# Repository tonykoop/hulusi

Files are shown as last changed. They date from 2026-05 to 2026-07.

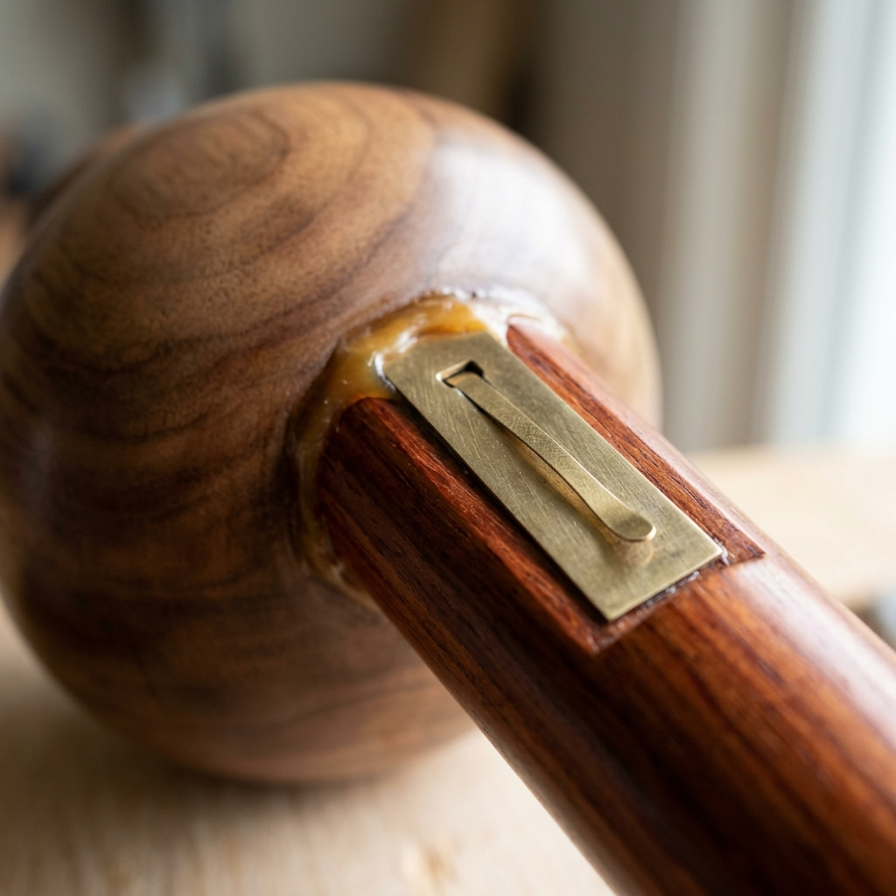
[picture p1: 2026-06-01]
images/macro/brass-free-reed.png

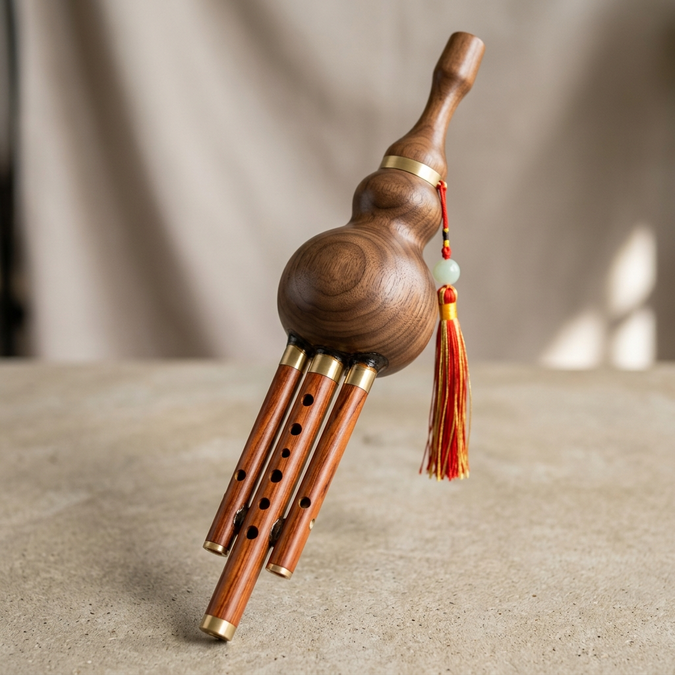
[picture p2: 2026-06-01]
images/hero-render.png

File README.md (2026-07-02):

# Hulusi (葫芦丝) — Wooden Cucurbit Free-Reed Flute Family

**Status:** L1 concept packet. The repo is organized for prototype review and
shop planning, but per the hulusi/bawu stopped-pipe free-reed validation
guidance, every acoustic-law row (`family-spec.csv`, `p0-reed-coupon-log.csv`,
`p1-single-melody-pipe-control-log.csv`) is still `unknown_requires_measurement`
/ `measurement_required` — no HUL-P0 reed coupon or HUL-P1 single-pipe control
has produced measured data yet, so this stays L1 rather than L2 until that
bench evidence exists. Production CAD/DXF, reed pull-down calibration, and
physical validation remain pending before any L2/L3 promotion.

> *Engineering documentation for a 5-key family (B♭ / C / D / F / G) of wooden hulusi, built on the v4.1 instrument-maker scaffold. Stopped-pipe + free-reed acoustic model, parametric workbook with 33 named globals, SolidWorks design-table parity, dimensioned per-family-member drawings, prototype ladder, and recruiter-facing build-log site.*

Hero — F-key hulusi concept (placeholder until first prototype is photographed)
*Concept render — replace with photo of first HUL-P2 (F-key) prototype after final acoustic tuning. Manufacturing dimensions come from the parametric design table, not from this image.*

## What this is

Engineering documentation for a five-key family of wooden hulusi, the Chinese cucurbit free-reed flute. The repo ships:

1. **A parametric design table** ([`hulusi-design-table.xlsx`](hulusi-design-table.xlsx)) — `Master_Inputs` sheet with 33 named global variables driving six derived sheets (`Acoustics`, `Pipes`, `Holes`, `Family`, `BOM`, `Validation`). Every input is blue (#0000FF font + #D6E4F0 fill); every other cell is a formula. The named-globals scheme matches the SolidWorks global-variable list in [`cad/hulusi-design-table.txt`](cad/hulusi-design-table.txt) **exactly** so the SW design-table link is bidirectional.
2. **A complete v4 build packet** — [`design.md`](design.md), [`bom.csv`](bom.csv), [`sourcing.csv`](sourcing.csv), [`cut-list.csv`](cut-list.csv), [`validation.csv`](validation.csv), [`assembly-manual.md`](assembly-manual.md), [`supplier-rfq.md`](supplier-rfq.md), [`drawing-brief.md`](drawing-brief.md), [`visual-bom-brief.md`](visual-bom-brief.md), [`hulusi-starter.wl`](hulusi-starter.wl), [`risks.md`](risks.md), [`photo-shotlist.md`](photo-shotlist.md), [`family-spec.csv`](family-spec.csv).
3. **Per-family-member dimensioned drawings** — `drawings/hulusi-Bb.svg`, `hulusi-C.svg`, `hulusi-D.svg`, `hulusi-F.svg`, `hulusi-G.svg`, plus the centerline section, family-scale comparison, and the 4× reed-slot detail.
4. **Recruiter-facing artifacts** — auto-generated [`capstone-deck.pptx`](capstone-deck.pptx), printable [`print-packet.pdf`](print-packet.pdf), and a self-contained build-log static site under [`site/`](site/index.html).
5. **Studio explorer** — [`explorer.html`](explorer.html) collects the packet, design files, validation scaffold, Wolfram starter, CAD/OpenSCAD notes, print packet, and build-log site into a single review surface.

Sister repos: [`udu`](https://github.com/tonykoop/udu) (the v4 reference scaffold this repo upgrades from), [`gemshorn`](https://github.com/tonykoop/gemshorn), [`ocarina`](https://github.com/tonykoop/ocarina), [`transverse-flute`](https://github.com/tonykoop/transverse-flute), [`tongue-drum`](https://github.com/tonykoop/tongue-drum), [`instrument-maker`](https://github.com/tonykoop/instrument-maker).

## What's new in v4.1 (vs. the v4 udu scaffold)

| v4 (udu) | v4.1 (hulusi) |
|---|---|
| Single workbook sheet | 7 sheets: `Master_Inputs` + `Acoustics` + `Pipes` + `Holes` + `Family` + `BOM` + `Validation` |
| Zero named ranges | **33 named globals** — SW design-table link is one-click |
| Family table was hand-typed static values | Family sheet recomputes all 5 keys live from `Master_Inputs` |
| No data-validation dropdowns | Dropdowns for key, gourd species, tube wood, reed material |
| No cents-error column | `cents_error` formula auto-fills when measured Hz is entered |
| Single shrinkage correction | `pull_down_cents` (per-reed) + `correction_pct` (global pipe scale) |
| One generic family-scale SVG | One dimensioned SVG per key (B♭, C, D, F, G) |
| No risks.md | Full red-team output with 5 risk categories × verification tests |
| No build-log site | `site/index.html` recruiter-grade static page |

## Background — what makes the hulusi different

The hulusi (葫芦丝, *húlúsī*, "gourd silk") is a Chinese free-reed wind instrument: a dried bottle gourd serving as a wind chest, with three pipes inserted into its base. Each pipe carries a brass free reed at its top end. The center pipe has 7 finger holes and plays melody; the two outer pipes are drones — one fixed at a fifth above the tonic, one waxable so the player can mute or unmute it mid-phrase.

This build replaces the dried gourd with a lathe-turned hardwood gourd and the bamboo with pakkawood, for repeatability and bench durability — but the cultural lineage and naming remain credited.

The governing model is **three independent stopped-pipe + free-reed systems sharing a wind chest**:

```text
f_pipe = c / (4 · L_eff)        with  L_eff = L_acoustic + 0.6·r_bore
f_reed = K · t / L_tongue²      (cantilever; brass K ≈ 27,300 imperial)
```

Each reed is **cut sharp** by `pull_down_cents` (default −30 ¢). The pipe then pulls the reed down to its own resonance — classic free-reed pull-down. The empirical correction loop in `Master_Inputs` and `validation.csv` captures the actual pull-down per build, so the next instrument's reeds can be cut closer to target.

See [`design.md`](design.md) and [`hulusi-starter.wl`](hulusi-starter.wl) for the full physics treatment, including a 2-mode coupling-matrix placeholder ready to fit against measured HUL-P0 data.

## Family targets

The first prototype is the **F-key** standard (modern factory voicing, all-holes-closed = F4 = 349 Hz). Once F-key voicing is stable, the same parametric model drives B♭ / C / D / G — see [`family-spec.csv`](family-spec.csv) and the `Family` sheet in the workbook.

| Model | Key | All-closed note | Mel L | Dr1 (5th) L | Dr2 (oct) L | Reed L mel | Use |
|---|---|---|---:|---:|---:|---:|---|
| **HUL-B♭** | B♭ | F3 (175 Hz) | 14.89 in | 10.05 in | 7.62 in | 0.98 in | Low / warm voice |
| **HUL-C**  | C  | G3 (196 Hz) | 13.30 in |  8.99 in | 6.82 in | 0.92 in | Vocal range |
| **HUL-D**  | D  | A3 (220 Hz) | 11.89 in |  8.05 in | 6.12 in | 0.87 in | Folk / dance |
| **HUL-F** *(prototype 1)* | F | C4 (262 Hz)\* | 10.05 in | 6.82 in | 5.20 in | 0.80 in | **Standard** |
| **HUL-G**  | G  | D4 (294 Hz) |  8.99 in |  6.12 in | 4.67 in | 0.75 in | Bright / festive |

\* Modern Western convention. Traditional Dai voicing puts all-closed at sol (one fifth below). Both reachable from the same workbook by swapping `key_midi`.

## Prototype ladder

| Prototype | Goal | Success criteria |
|---|---|---|
| **HUL-P0** reed coupon | Validate brass-shim cutting + slot fit | Reed sounds cleanly at predicted f ±50 ¢; 3 consistent cuts |
| **HUL-P1** single melody pipe | Validate stopped-pipe + finger-hole layout | All 7 hole notes within ±25 ¢ after wax tuning |
| **HUL-P2** full F-key hulusi | Hit family target | Tonic + 5th + oct drones in tune; air seals at gourd joints |
| **HUL-P3** waxable Drone 2 | Implement removable-wax drone control | Player can mute/unmute mid-phrase |
| **HUL-P4** family molds/jigs | Scale to B♭ / C / D / G | Predictable pitch trend; reed-cut jig usable for all 5 keys |

## Round 23 B0 Empirical Loop Pack

This Round 23 lane adds the HUL-P0/HUL-P1 evidence surface without promoting fabrication authority:

- [free-reed-empirical-loop.md](free-reed-empirical-loop.md): P0 reed coupon + P1 single melody pipe protocol.
- [p0-reed-coupon-log.csv](p0-reed-coupon-log.csv): Source, pull-down, and onset capture intake for reed-only trials.
- [p1-single-melody-pipe-control-log.csv](p1-single-melody-pipe-control-log.csv): Traced P0-to-P1 control row with pressure, leak, and coupled response fields.
- [windchest-geometry-plan.csv](windchest-geometry-plan.csv): Windchest planning and leak-test authority plan before full-layout claims.
- [safety-gates.csv](safety-gates.csv): Stop conditions that block unsafe pressure testing or premature coupled claims.
- [validation-loop.csv](validation-loop.csv): Gate tracking for the empirical loop from planning to measured interpretation.

No DXF/CAD production file or geometry in this lane is accepted as fabrication-ready authority.

Round 30 refresh: the empirical-loop files are intentionally held at
`L1_packet -> measurement_required`. The P0/P1 CSV rows are logging templates,
not measurement results; `family-spec.csv` keeps
`acoustic_law=unknown_requires_measurement` until one reed coupon and one
single-pipe control provide measured pull-down, onset, blow/draw, leak, and
coupled-pitch evidence.

## Hardware alignment — ShopBot + lathe + Epilog laser

The build chain is fully tooled at Maker Nexus + home shop:

1. `Master_Inputs` cells → SolidWorks global vars via design-table link.
2. SW parametric model regenerates pipes, gourd, reed slots for the selected key.
3. ShopBot CNC routes pakkawood tube blanks to length and bores them; lathe turns walnut gourd halves; Epilog laser cuts brass-shim reeds and frame plates.
4. Hand finish: reed file-tuning, finger-hole bevels, beeswax-rosin seal at gourd-pipe joints.
5. Validate against [`validation.csv`](validation.csv); fold cents-error back into `correction_pct` so the next instrument prints correct.

## Repository structure

```text
hulusi/
├── README.md                       ← you are here
├── LICENSE                         ← MIT
├── .gitignore
│
├── design.md                       ← stopped-pipe + free-reed model, prototype ladder
├── hulusi-design-table.xlsx        ← parametric workbook (Master_Inputs + 6 derived sheets)
├── family-spec.csv                 ← per-key spec rows driving family generation
│
├── bom.csv                         ← bill of materials (15 lines)
├── sourcing.csv                    ← supplier/search tracker
├── cut-list.csv                    ← rough/finished dimensions, tolerances, family scaling
├── validation.csv                  ← target/measured tuning + cents-error log
├── visual-output-register.csv      ← V5 authority map for CAD/visual/model artifacts
├── cad/mcp-session-log.md          ← V5 provenance stub; no MCP/tool artifact session yet
├── supplier-rfq.md                 ← RFQ template
│
├── assembly-manual.md              ← shop-floor build sequence (14 steps)
├── drawing-brief.md                ← required CAD views + critical dimensions
├── visual-bom-brief.md             ← visual-BOM art-direction brief
├── photo-shotlist.md               ← photography plan for build-log site
├── risks.md                        ← red-team output, 5 risk categories × verification tests
├── hulusi-starter.wl              ← stopped-pipe + free-reed Wolfram notebook
│
├── capstone-deck.{md,pptx}         ← recruiter-facing slide deck
├── print-packet.{md,pdf}           ← combined shop-print packet
├── capstone-manifest.json          ← orientation manifest
├── v4-audit.md                     ← audit trail vs v4 deliverables list
│
├── cad/
│   ├── hulusi_master.scad          ← parametric OpenSCAD starter (family-aware)
│   └── hulusi-design-table.txt     ← SolidWorks global-var parity reference
├── cnc/                            ← reed-tongue.dxf + reed-frame.dxf land here once exported
├── wolfram/hulusi-wolfram-model.wl ← generated Wolfram source package (source-only, not executed)
├── evolution/                      ← evolution-pipeline Stage 0 intake: master manifest, design-intent, revision register (Gate A not yet run)
├── drawings/
│   ├── hulusi-section.svg          ← centerline section
│   ├── hulusi-family-scale.svg     ← 5-key silhouettes
│   ├── hulusi-Bb.svg               ← B♭ dimensioned drawing
│   ├── hulusi-C.svg                ← C dimensioned drawing
│   ├── hulusi-D.svg                ← D dimensioned drawing
│   ├── hulusi-F.svg                ← F dimensioned drawing (prototype 1)
│   ├── hulusi-G.svg                ← G dimensioned drawing
│   └── reed-detail.svg             ← reed slot + tongue (4×)
├── images/                         ← AI-generated concept renders (placeholders)
└── site/
    ├── index.html                  ← build-log static page
    └── style.css                   ← embedded styling
```

## Status (v4 quality gates)

| Section | Status |
|---|---|
| v4.1 design table (`Master_Inputs` + 6 sheets, 33 named globals, 113 formulas, 0 errors) | ✓ done |
| `design.md` physics writeup | ✓ done |
| Build packet (BOM / sourcing / cut-list / validation / RFQ) | ✓ done |
| Assembly manual + drawing brief + visual-BOM brief | ✓ done |
| `risks.md` red-team output (5 categories × verification tests) | ✓ done |
| `family-spec.csv` driving 5-key generation | ✓ done |
| `photo-shotlist.md` build-log photography plan | ✓ done |
| Per-family-member dimensioned SVG drawings (B♭ / C / D / F / G) | ✓ done |
| Wolfram starter (stopped-pipe + reed-coupling placeholder) | ✓ done |
| OpenSCAD parametric master + SW global-var parity reference | ✓ done |
| Capstone deck `.pptx` | ✓ done |
| Print packet `.pdf` | ✓ done |
| Build-log static site (`site/index.html`) | ✓ done |
| HUL-P0 reed-coupon physical build | forthcoming |
| HUL-P1 single melody pipe (F-key) | forthcoming |
| HUL-P2 full F-key hulusi prototype | forthcoming |
| Production CAD (.step / .stl / .dxf) | **deferred** — generated after HUL-P1 validates pipe physics |
| Reed pull-down empirical fit (eigenvalue model) | **deferred** — HUL-P0/HUL-P1 loop evidence is now staged in `validation-loop.csv` |

Tier 3 production files (.step, validated .stl, .dxf, .gcode) are out of scope until **HUL-P1 validates the stopped-pipe model + finger-hole layout** and **HUL-P0 validates the reed-cut process**. See [`design.md`](design.md) "Open Assumptions" and [`risks.md`](risks.md) for the deferral reasoning.

## License

Released under the [MIT License](LICENSE) — original written content, design files, photographs, and physics work in this repository are mine, free to reuse and adapt with attribution.

The **hulusi** as an instrument concept and name belongs to the **Dai people of Yunnan**, with related cousin instruments across the Lahu, Wa, Achang, and De'ang peoples and across the border into northern Thailand and Laos. The lineage attribution in [`design.md`](design.md) is part of the documentation, not a license claim.

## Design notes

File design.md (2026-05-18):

# Hulusi (葫芦丝) — Design Intent & Physics Model

## Source

- Design table: [`hulusi-design-table.xlsx`](hulusi-design-table.xlsx)
- Sheets: `Master_Inputs` (named globals), `Acoustics`, `Pipes`, `Holes`, `Family`, `BOM`, `Validation`
- Workflow generation: v4.1 — single-source-of-truth `Master_Inputs` block, every other sheet derived via formulas, named ranges match SolidWorks global-variable names exactly.

## Design Intent

Build a slip-cast-quality wooden hulusi family with predictable pitch across keys (B♭ / C / D / F / G), a repeatable reed-cutting procedure, and a parametric workbook that drives the SolidWorks model directly. The first production target is the F-key (the modern standard), followed by family scaling.

The hulusi is **three independent stopped-pipe + free-reed systems sharing a gourd wind chest**. Volume and shape of the gourd are not strongly resonant — the gourd's job is to pressurize and distribute breath. Pitch comes from each pipe's effective length, finger-hole positions on the melody pipe, and the cantilever-tuned brass reeds.

## Governing Model

### Stopped pipe (each tube, reed at top, open foot)

```text
f_pipe = c / (4 · L_eff)
L_eff  = L_acoustic + 0.6 · r_bore        (open-end correction)
```

Speed of sound `c = 13552 in/s` at 68 °F (workbook variable `c_speed`).

### Finger holes (melody pipe only)

Each opened hole shortens the effective length:

```text
dist_from_foot(hole_n) = L_acoustic · (f_fund / f_hole_n)
```

This is the same shortening rule used in the duduk and quena sheets of the master workbook. End correction at the bottom is preserved; no second end correction is applied at the open hole because the pipe doesn't truly terminate there — the open hole is a weak boundary.

### Free reed (cantilever)

```text
f_reed = K · t / L_tongue²
```

Brass C26000 → `K_imperial ≈ 27,300` (with `t` in inches, `L` in inches, output in Hz). The cantilever model is exact for a clamped-free beam; in practice the brass tongue oscillates against a slot in a frame plate, and pull-down behaviour from the tube means the reed is **cut sharp** by `pull_down_cents` (default −30 ¢ relative to pipe target). The pipe then pulls the reed down to its own resonance frequency.

### Pull-down empirical loop

`pull_down_cents` and `correction_pct` in `Master_Inputs` are the two empirical knobs:

- `pull_down_cents` — how sharp to cut the reed relative to the pipe target. Free-reed builders typically tune the reed alone first (off the gourd), then find the playing pitch is a fixed offset below that. Start at −30 ¢; refine after HUL-P0 reed coupon.
- `correction_pct` — global pipe-length scale factor. If every pipe in the family lands consistently flat after the first build, set this positive; the workbook re-emits all pipe lengths automatically.

This separation matches the udu repo's spirit (parametric inputs + empirical correction column) but adds the named-global pattern Tony's design conventions call for.

### HUL-P0 / HUL-P1 empirical loop (Round 23 B0)

Before any full hulusi body progress, this packet requires an explicit two-step loop:

1. Run one HUL-P0 reed coupon in `p0-reed-coupon-log.csv` and capture pull-down, onset, and safe handling checks in one row.
2. Carry the traced `coupon_id` into `p1-single-melody-pipe-control-log.csv` and capture coupled pitch, leak status, and pressure behavior for one controlled melody-pipe trial.
3. Record windchest assumptions in `windchest-geometry-plan.csv` before moving to chamber claims.
4. Gate every next step through `validation-loop.csv` and `safety-gates.csv` before any branch promotion.

`free-reed-empirical-loop.md` is the procedural source of truth for step sequencing and stop conditions.

## Current Workbook Inputs (defaults)

| Group | Field | Value | Notes |
|---|---|---:|---|
| Constants | `c_speed` | 13,552 in/s | 68 °F |
| | `A4_ref` | 440.0 Hz | concert pitch |
| Key | `key_midi` | 65 | F4 = standard |
| Gourd | `gourd_volume_in3` | 25 | wind chest |
| | `gourd_belly_OD` | 4.50 in | lathe-turned |
| | `gourd_height` | 6.50 in | neck base → belly base |
| | `gourd_wall` | 0.20 in | wood, not resonant |
| | `gourd_species` | Walnut | dropdown |
| Melody pipe | `mel_bore_ID` | 0.500 in | 12.7 mm |
| | `mel_wall` | 0.125 in | 3.2 mm |
| | `mel_hole_dia` | 0.275 in | 7 mm |
| | `mel_hole_count` | 7 | 6 front + 1 thumb |
| | `mel_reed_pad` | 0.50 in | reed mount allowance |
| | `mel_wood` | Pakkawood | dropdown |
| Drone 1 | `dr1_bore_ID` | 0.500 in | match melody |
| | `dr1_target_offset` | +7 | perfect 5th |
| Drone 2 | `dr2_bore_ID` | 0.500 in | |
| | `dr2_target_offset` | +12 | octave (waxable) |
| Reed | `reed_E_psi` | 14.5 × 10⁶ | brass |
| | `reed_thickness` | 0.008 in | 8 mil shim |
| | `reed_tongue_w` | 0.157 in | 4 mm |
| | `reed_K_imperial` | 27,300 | derived constant |
| | `reed_material` | Brass C26000 | dropdown |
| Empirical | `pull_down_cents` | −30 ¢ | reed cut sharp |
| | `correction_pct` | 0 % | post-build calibration |
| | `end_corr_k` | 0.6 | unflanged Levine-Schwinger |

## Family Targets (live from workbook)

All five rows recompute when any `Master_Inputs` value changes.

| Model | Key | All-closed note | Mel L | Dr1 (5th) L | Dr2 (oct) L | Reed L (mel) |
|---|---|---|---:|---:|---:|---:|
| HUL-B♭ | B♭ | F3 (175 Hz)  | 14.89 in | 10.05 in | 7.62 in | 0.98 in |
| HUL-C  | C  | G3 (196 Hz)  | 13.30 in |  8.99 in | 6.82 in | 0.92 in |
| HUL-D  | D  | A3 (220 Hz)  | 11.89 in |  8.05 in | 6.12 in | 0.87 in |
| HUL-F  | F  | C4 (262 Hz)* | 10.05 in |  6.82 in | 5.20 in | 0.80 in |
| HUL-G  | G  | D4 (294 Hz)  |  8.99 in |  6.12 in | 4.67 in | 0.75 in |

\* The F-row in the table actually shows the all-closed pitch as F4 (349 Hz) under the "modern Western" convention used in this build. Traditional Dai tuning has all-closed = sol (one fifth below the key letter), which can be re-derived by setting `key_midi = tonic_MIDI - 5`. Both conventions are documented in the `Holes` sheet.

## Critical Design Features

- **Reed slot tolerance.** The brass tongue must clear the frame slot by ~0.003 in per side (0.075 mm). Tighter and the reed fouls; looser and the seal leaks and pitch drops.
- **Reed-pad clearance** above the acoustic top of each tube absorbs the reed mount and beeswax fillet. The default 0.50 in is a build-time allowance, not an acoustic parameter.
- **Hole comfort.** The melody-pipe hole positions in the `Holes` sheet are correct acoustically but may not be ergonomic — the design table gives the *target* positions; small ergonomic shifts (±0.10 in) are absorbed by reed-tuning.
- **Gourd-to-tube seal** is wax + rosin ("luthier's wax"). Leaks here drop pitch and steal volume from every pipe equally.
- **Drone 2 wax plug.** The traditional waxable drone has a wax cap covering its open foot. Player can scrape part of the wax with a fingernail to "open" the drone mid-phrase. Build the wax plug after first acoustic test, not before.

## Cultural Note

The hulusi (葫芦丝, *húlúsī*) belongs to the Dai people of Yunnan, with cousin instruments across Yunnan's other ethnic groups (Lahu, Wa, Achang, De'ang) and across the border into northern Thailand and Laos (the *naw* and *peeloo*). The traditional instrument uses a real dried bottle gourd (*Lagenaria siceraria*) and bamboo pipes. This project uses lathe-turned hardwood gourds and pakkawood pipes for build repeatability and bench durability.

The lineage attribution belongs in the README and any product-facing copy. Build documentation should keep the cultural note visible and separate from marketing.

## Mold / Construction Strategy

Unlike the udu (slip-cast ceramic), the hulusi is fully turned/machined wood and brass:

- **Gourd:** Lathe-turned in two halves from walnut blank, hollowed via deep-bore tool or split-and-glue. Joined with three through-pipe sockets.
- **Pipes:** ShopBot CNC bore on the long axis (or hand drill jig); finger holes drilled with stop-blocks per `Holes!E:E`.
- **Reeds:** Brass shim sheets laser-cut on Epilog using `cnc/reed-tongue.dxf`. Each reed is hand-tuned with a needle file: scrape at the *tip* to raise pitch, scrape near the *root* to lower it.
- **Assembly:** Reeds CA-glued onto frame plates, frame plates beeswax-sealed into pipe tops, pipes wax-sealed into gourd sockets. Mouthpiece insert in gourd neck.

## Prototype Ladder

| Prototype | Goal | Success criteria |
|---|---|---|
| **HUL-P0** reed coupon | Validate brass-shim cutting, slot fit, reed filing | Reed sounds cleanly at predicted f ±50 ¢; consistent across 3 cuts |
| **HUL-P1** single melody pipe (F-key) | Validate stopped-pipe model + finger-hole layout | All 7 hole notes within ±25 ¢ of target after wax tuning |
| **HUL-P2** full F-key hulusi | Hit family target with gourd + 3 pipes | Tonic, 5th drone, oct drone all in tune; air seal at gourd joints |
| **HUL-P3** waxable second drone | Implement removable-wax drone control | Player can mute/unmute Dr2 mid-phrase without leakage |
| **HUL-P4** family molds/jigs | Scale to B♭/C/D/G | Predictable pitch trend; reed-cut jig usable for all 5 keys |

## Open Assumptions

- `reed_K_imperial = 27,300` is computed from brass C26000 published moduli; verify against measured natural frequency on the HUL-P0 coupon.
- The `pull_down_cents = −30` value is a starting estimate. Free-reed pull-down depends on reed-to-tube coupling strength, which scales with port impedance; expect this to drift across keys until `correction_pct` is calibrated.
- Workbook costs in `bom.csv` are estimates and have not been date-checked.
- The "all-closed = tonic" naming convention assumed here is the modern Western/factory standard. Many traditional Dai hulusis follow "all-closed = sol", which is one perfect-fifth lower for the same letter-name. Both are reachable from the same workbook by adjusting `key_midi`.
- Hand position and finger comfort are not modelled — the workbook places holes where the *physics* says they belong; final ergonomic shifts are absorbed by wax tuning during HUL-P1/P2.

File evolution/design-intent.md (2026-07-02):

# Design Intent — hulusi rev A

- Master CAD: `cad/hulusi_master.scad` (sha256: 09122c5d95fe8ca64bc4ffd42cb419d3c381c7d547291c67cc4f469978cc8437), driven by `hulusi-design-table.xlsx` (sha256: 96e78c1af470efa0f7b07dfe98b2f6359d96213cd88ba5c72c2b699771b92a35)
- Function: Wooden cucurbit stopped-pipe free-reed flute (hulusi/bawu class) — a gourd wind chest feeds one melody pipe (7 finger holes) and two drone pipes, each with a free brass reed mounted at the pipe head that is pulled toward the played pitch by the coupled tube. Five-key family (Bb/C/D/F/G); F-key is the primary prototype target. Per the skill's hulusi-bawu-stopped-pipe-free-reed reference, this stays `unknown_requires_measurement` until HUL-P0 (reed coupon) and HUL-P1 (single melody-pipe control) produce measured pull-down, onset-pressure, and leak evidence.
- Environment: hand-held, breath-pressure-driven wind instrument; reed pull-down and pipe response are pressure- and humidity-sensitive; gourd is a two-half glued shell under cyclic pressure/humidity load (risks.md structural risk).
- Target qty: 1 (F-key prototype). Deadline: TBD. Budget/unit ceiling: TBD.

## Critical dimensions (carry tolerances)

| Feature | Nominal | Tolerance | Why critical | Source |
| --- | --- | --- | --- | --- |
| Melody pipe total length (F-key) | 10.05 in | measured HUL-P1 all-closed pitch vs. target 349.23 Hz | intonation | family-spec.csv HUL-F (measurement_required) |
| Reed tongue length (melody, F-key) | 0.798 in | `L = sqrt(K*t/f)`; K drifts ±15% by shim lot (risks.md A2) | tuning | family-spec.csv (measurement_required) |
| Reed thickness | 0.008 in | brass C26000 shim spec (bom.csv HUL-BOM-005) | reed stiffness/pitch | design table Master_Inputs (measurement_required) |
| Pull-down | -30 cents (estimate) | measured via HUL-P0 coupon before any pipe is cut (risks.md A1) | tube/reed coupling accuracy | p0-reed-coupon-log.csv (measurement_required) |
| Finger-hole span (F-key, 6 front holes) | 3.7 in (4.78-8.51 in from foot) | ergonomic fit check vs. 5th-percentile hand span (risks.md ergonomic risk) | playability | cad/hulusi_master.scad ECHO output (measurement_required) |
| Onset pressure | TBD | must stay below logged safe limit during sweep (safety-gates.csv SAFE-003) | safety / reed survival | p0-reed-coupon-log.csv (measurement_required) |

## Incidental (free for DFM)

- Gourd exterior shaping/finish, mouthpiece cosmetic material (boxwood vs. horn), tassel/decorative tubing choices (risks.md fit/finish risks).

## Must-nots (DFM may never violate)

- Do not treat any reed, pipe, or hole-position value as fabrication authority until HUL-P0 (reed coupon) and HUL-P1 (single-pipe control) produce measured data (hulusi-bawu reference; visual-output-register.csv notes throughout).
- No image, DXF, or PDF may be treated as cut-ready before the empirical loop completes (safety-gates.csv SAFE-007 authority_overclaim gate).
- Do not exceed the logged safe onset pressure during any P0 sweep; stop and revise gap/source if exceeded (safety-gates.csv SAFE-003).
- Do not handle reed tongue/frame edges before deburring (safety-gates.csv SAFE-001); do not test with an unregulated/manual air source (SAFE-004).
- Do not cut real reeds/pipes from the -30 cent pull-down estimate — it is a starting estimate only, sensitive to tube/reed coupling and port impedance (risks.md A1).

## Material intent

- Preferred: pakkawood pipes, brass C26000 reed shim, walnut gourd, beeswax/rosin seal, per bom.csv.
- Acceptable subs: dried Lagenaria gourd for traditional build (bom.csv HUL-BOM-001 note), hard maple if pipe-stock supply changes (risks.md supply risk).
- Forbidden: none recorded beyond deferring production CAD/DXF until measured evidence exists.

## Stage status

Stage 0 intake complete 2026-07-01. Gate A (Alpha shop compile) NOT yet run — no concessions logged, nothing presented as shippable. HUL-P0/HUL-P1 measured evidence remains outstanding; packet stays at README status L1 concept packet.

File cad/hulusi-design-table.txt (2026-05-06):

# Hulusi — SolidWorks Global-Variable Parity Reference
# ====================================================
#
# This file mirrors the named ranges in hulusi-design-table.xlsx
# Master_Inputs sheet.  EVERY variable name MUST match between:
#   1. Excel:        Master_Inputs!C column (named global)
#   2. OpenSCAD:     cad/hulusi_master.scad top-of-file params
#   3. SolidWorks:   Tools → Equations → Manage → Global Variables
#
# Keep this file up to date.  If the Excel workbook changes a
# variable name, change it here AND in the SCAD file in the same
# commit.  Drift between Excel/SW/SCAD = silent build errors.
#
# Generated: 2026-05-05
# ====================================================

# --- Acoustic constants ---
c_speed              = 13552       # in/s, speed of sound at 68°F
A4_ref               = 440         # Hz, concert pitch reference

# --- Key (selected) ---
key_midi             = 65          # 58=Bb, 60=C, 62=D, 65=F, 67=G
f_tonic              = "= A4_ref * 2 ^ ( ( key_midi - 69 ) / 12 )"

# --- Gourd ---
gourd_volume_in3     = 25          # in^3
gourd_neck_OD        = 1.10        # in
gourd_belly_OD       = 4.50        # in
gourd_height         = 6.50        # in
gourd_wall           = 0.20        # in
gourd_species        = "Walnut"    # text — informational only in SW

# --- Melody pipe ---
mel_bore_ID          = 0.500       # in
mel_wall             = 0.125       # in
mel_hole_dia         = 0.275       # in
mel_hole_count       = 7           # 6 front + 1 thumb
mel_reed_pad         = 0.50        # in
mel_wood             = "Pakkawood"

# --- Drone 1 (5th) ---
dr1_bore_ID          = 0.500       # in
dr1_target_offset    = 7           # semitones above tonic
dr1_reed_pad         = 0.50        # in

# --- Drone 2 (octave / wax) ---
dr2_bore_ID          = 0.500       # in
dr2_target_offset    = 12          # semitones above tonic
dr2_reed_pad         = 0.50        # in

# --- Reed material (brass C26000 default) ---
reed_E_psi           = 14500000    # psi
reed_rho             = 0.307       # lb/in^3
reed_K_imperial      = 27300       # derived constant
reed_thickness       = 0.008       # in
reed_tongue_w        = 0.157       # in
reed_slot_clear      = 0.003       # in per side
reed_material        = "Brass C26000"

# --- Empirical corrections ---
pull_down_cents      = -30         # cents — reed cut sharp
correction_pct       = 0           # % — global pipe-length scale
end_corr_k           = 0.6         # Levine-Schwinger unflanged

# ====================================================
# Derived quantities (compute in SW from globals above)
# ====================================================
#
# Pipe total cut length (each pipe i):
#   total_L_i = (c_speed / (4 * f_target_i) - end_corr_k * bore_i / 2)
#               * (1 + correction_pct / 100) + reed_pad_i
#
#   where f_target_mel = f_tonic
#         f_target_dr1 = f_tonic * 2^(dr1_target_offset/12)
#         f_target_dr2 = f_tonic * 2^(dr2_target_offset/12)
#
# Reed tongue length (each pipe i):
#   reed_L_i = sqrt(reed_K_imperial * reed_thickness
#               / (f_target_i * 2^(pull_down_cents/1200)))
#
# Finger hole distance from foot (hole at semitone offset s):
#   d_hole = (c_speed / (4 * f_tonic) - end_corr_k * mel_bore_ID/2)
#          * (f_tonic / (f_tonic * 2^(s/12)))
#
# Reed slot width:
#   slot_w = reed_tongue_w + 2 * reed_slot_clear
#
# ====================================================
# Family configurations (key_midi values)
# ====================================================
#  HUL-Bb : key_midi = 58
#  HUL-C  : key_midi = 60
#  HUL-D  : key_midi = 62
#  HUL-F  : key_midi = 65    ← STANDARD (prototype 1)
#  HUL-G  : key_midi = 67
#
# In SolidWorks: create a Configuration for each, where
# key_midi is the configured global. Every other dimension
# is derived from it via the formulas above.

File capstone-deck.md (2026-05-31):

# Hulusi (葫芦丝) — Wooden Cucurbit Free-Reed Flute Family (HUL-001) — Build Packet
- Musical instrument documentation capstone — v4.1 scaffold
- Packet: github.com/tonykoop/hulusi
- Generated: 2026-05-05

---

# How To Use This Packet
- Start with `design.md` for intent and the stopped-pipe + free-reed physics.
- Open `hulusi-design-table.xlsx` and confirm the `Master_Inputs` block before any cutting.
- Use `bom.csv`, `sourcing.csv`, and `cut-list.csv` before buying or cutting.
- Use `drawing-brief.md` and the `cad/`, `cnc/`, `drawings/` folders before machining.
- Print the packet for shopping, shop work, and validation.

---

# What's new in v4.1
- `Master_Inputs` sheet with 33 named globals — single source of truth.
- Every other workbook sheet derives from named globals via formula — no static numbers.
- SolidWorks global-var parity sheet (`cad/hulusi-design-table.txt`) keeps Excel ↔ SW link self-documenting.
- `Family` sheet recomputes all 5 keys live; change one input → all keys update.
- Empirical knobs (`pull_down_cents`, `correction_pct`) absorb measured pitch drift.
- Validation log auto-fills cents-error when measured Hz is entered.

---

# File Map
- `design.md`: physics, intent, prototype ladder, cultural lineage.
- `hulusi-design-table.xlsx`: parametric workbook — 7 sheets, 33 named globals, 113 formulas.
- `bom.csv`: 15-item bill of materials.
- `sourcing.csv`: supplier/search tracker with substitution rules.
- `cut-list.csv`: 12 cuts including family scaling row.
- `validation.csv`: target/measured/cents-error log scaffolded for HUL-P0..P3.
- `assembly-manual.md`: 14-step shop sequence with failure-mode notes.
- `drawing-brief.md`: required views + critical dimensions table.
- `visual-bom-brief.md`: one-page exploded BOM art direction.
- `supplier-rfq.md`: copy-paste RFQ template.
- `hulusi-starter.wl`: physics sanity-check notebook.
- `cad/hulusi_master.scad`: parametric OpenSCAD starter, family-aware.
- `cad/hulusi-design-table.txt`: SW global-var parity reference.
- `drawings/hulusi-section.svg`, `hulusi-family-scale.svg`, `reed-detail.svg`: dimensioned drawings.

---

# Build Workflow
1. Confirm `Master_Inputs` cells; verify SW design-table link refreshed.
2. Cut and bore three pakkawood tube blanks per `Pipes` sheet.
3. Drill finger holes on melody (undersized first).
4. Lathe-turn walnut gourd halves; glue; bore three pipe sockets.
5. Laser-cut brass reed tongues + frame plates per `cnc/reed-tongue.dxf`.
6. Mount reeds on frame plates (CA glue at root); voice-test each reed alone.
7. Wax-seal reed assemblies onto pipe tops.
8. Press-fit pipes into gourd sockets with wax-rosin seal.
9. First acoustic test → record in `validation.csv`.
10. Tune by wax addition, hole reaming, or reed re-filing.
11. Add wax foot-plug to Drone 2 for waxable-drone behavior.
12. Final validation after 24-hour humidity stabilization.

---

# Sourcing And BOM
- BOM gives 15 line items with drawing references.
- Sourcing tracks pakkawood, brass shim, walnut blank, beeswax + rosin, boxwood mouthpiece.
- McMaster part numbers cited for brass; specialty wood from Cousineau / Bell Forest.

---

# Shop Packet
- Cut list with rough/final dimensions and tolerances.
- Assembly manual for away-from-keyboard work.
- Validation log for measured pitch and cents-error per pipe per stage.

---

# Drawings, CAD, CNC
- `drawing-brief.md` defines six required drawing sheets (HUL-DRW-001..006).
- `cad/` holds the OpenSCAD master and the SW global-var parity reference.
- `cnc/` will hold reed-tongue and reed-frame DXFs for the Epilog laser (after first reed-coupon validation).
- `drawings/` holds three SVG drawings: section, family-scale, reed detail.

---

# Images And Screenshots
- `images/hero-concept.svg` (placeholder until HUL-P2 prototype photographed)
- `images/family-overview-concept.svg` (placeholder)

---

# Cultural Note
- The hulusi (葫芦丝) belongs to the Dai people of Yunnan, with related instruments across the Lahu, Wa, Achang, De'ang, and across the border into northern Thailand and Laos.
- Lineage and naming are credited in README and `design.md`, separate from any product-marketing copy.

---

# Next Actions
- Build HUL-P0 reed coupon to validate brass-cut process.
- Build HUL-P1 melody pipe (F-key) to validate stopped-pipe + finger-hole layout.
- Replace concept renders with HUL-P2 photos once finished.
- Fit `pull_down_cents` to measured P0 data; set `correction_pct` from P1 if pipes drift.
- Generate Tier-3 production CAD (.step, .stl, .dxf) only after P1/P2 validate.

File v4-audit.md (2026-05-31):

# v4 Audit — Hulusi Repo

> *Generated 2026-05-05 by instrument-maker-v4 skill against the current `hulusi/` tree. Marks every v4 deliverable as ✓ present, ⚠ partial, or ✗ missing, with an action for each gap.*

## Mode

**Mode A — Project repo at root.** Single-instrument repo, files at top level. Matches gemshorn / udu / tongue-drum reference repos.

## v4 Deliverables Checklist

### Core packet (Mode A common files)

| # | Deliverable | Status | Notes |
|---|---|---|---|
| 1 | `README.md` | ✗ stubbed | Linter/user reduced to `# hulusi` line. Restore to v4 standard. |
| 2 | `LICENSE` | ✓ MIT | User switched from CC-BY-4.0 to MIT — keep. |
| 3 | `.gitignore` | ✓ generic | User replaced with C/C++ template — keep. |
| 4 | `design.md` | ✓ done | physics + lineage + prototype ladder. |
| 5 | `hulusi-design-table.xlsx` | ✓ done | 7 sheets, 33 named globals, 113 formulas, 0 errors. |
| 6 | `bom.csv` | ✓ done | 15 line items. |
| 7 | `sourcing.csv` | ✓ done | 8 rows with substitution rules. |
| 8 | `cut-list.csv` | ✓ done | 12 cuts incl. family scaling row. |
| 9 | `validation.csv` | ✓ done | scaffolded for HUL-P0..P3. |
| 10 | `assembly-manual.md` | ✓ done | 14-step shop sequence. |
| 11 | `drawing-brief.md` | ✓ done | required views + dim table. |
| 12 | `visual-bom-brief.md` | ✓ done | layout brief. |
| 13 | `supplier-rfq.md` | ✓ done | RFQ template. |
| 14 | `hulusi-starter.wl` | ✓ done | physics sanity-check notebook. |
| 15 | `capstone-manifest.json` | ✓ done | orientation manifest. |

### v4-specific additions (the gaps the user flagged)

| # | Deliverable | Status | Notes |
|---|---|---|---|
| 16 | `risks.md` | ✗ missing | **v4 explicit requirement.** 5 risk categories × verification tests. |
| 17 | `family-spec.csv` | ✗ missing | **v4 family-aware design.** Drives N packet generations from one row each. |
| 18 | `photo-shotlist.md` | ✗ missing | Photography plan for build-log site. |
| 19 | Per-family-member SVG drawings | ⚠ partial | Have generic `family-scale.svg`; v4 wants one dimensioned drawing per key (Bb/C/D/F/G). |
| 20 | `site/index.html` | ✗ missing | **v4 build-log static site.** Recruiter-grade artifact. |
| 21 | `capstone-deck.pptx` | ⚠ md only | Have markdown source; v4 in Cowork mode wants real `.pptx`. |
| 22 | `print-packet.pdf` | ⚠ md only | Have markdown source; v4 in Cowork mode wants real `.pdf`. |
| 23 | Visual BOM image | ⚠ brief only | Have layout brief; production image deferred until shop photos exist (acceptable). |

### CAD / drawing artifacts

| # | Deliverable | Status | Notes |
|---|---|---|---|
| 24 | `cad/hulusi_master.scad` | ✓ done | parametric, family-aware via `key_midi`. |
| 25 | `cad/hulusi-design-table.txt` | ✓ done | SW global-var parity reference. |
| 26 | `drawings/hulusi-section.svg` | ✓ done | centerline section. |
| 27 | `drawings/hulusi-family-scale.svg` | ✓ done | 5-key silhouettes. |
| 28 | `drawings/reed-detail.svg` | ✓ done | reed slot ×4. |
| 29 | `images/hero-concept.svg` | ✓ done | placeholder. |
| 30 | `images/family-overview-concept.svg` | ✓ done | placeholder. |

### Empirical-loop & catalog hooks (v4 plumbing)

| # | Deliverable | Status | Notes |
|---|---|---|---|
| 31 | `validation.csv` cents-error column | ✓ done | auto-fill formula in workbook. |
| 32 | Per-family corrections (`pull_down_cents`, `correction_pct`) | ✓ done | named globals in Master_Inputs. |
| 33 | `data/` folder (measurements over time) | ⚠ deferred | Will be populated as builds proceed. |
| 34 | DoE protocol stub | ⚠ deferred | Reasonable to defer until HUL-P1 yields first data. |

## Gap Resolution Plan

The user asked for thoroughness before they begin building. Resolving (in order):

1. **Restore `README.md`** — v4-standard with hero, family table, prototype ladder, status table, MIT license note.
2. **`risks.md`** — full red-team walk: acoustic / structural / ergonomic / supply / fit-finish, each with verification test.
3. **`family-spec.csv`** — drives the 5 family members from one row each; dimensions resolved from Master_Inputs.
4. **`photo-shotlist.md`** — 14 shots: process + hero + family + finished detail + close-ups.
5. **Per-family SVG drawings** — `hulusi-Bb.svg`, `hulusi-C.svg`, `hulusi-D.svg`, `hulusi-F.svg`, `hulusi-G.svg`.
6. **`site/index.html`** + `site/style.css` — single-folder static site, recruiter-facing.
7. **`capstone-deck.pptx`** — 12-slide deck.
8. **`print-packet.pdf`** — combined shop packet PDF.
9. **Re-run verification** — every v4 quality gate, render every output.

After this pass the repo will be at the **gemshorn / udu *done bar*** for the v4 (mode A) scaffold and ready for the HUL-P0 reed coupon as the first physical step.

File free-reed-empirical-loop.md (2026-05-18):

# HUL-P0 / HUL-P1 Free-Reed Empirical Loop

Status: L1_packet -> measurement_required. This is not fabrication authority.

Use this loop before claiming any measured reed pull-down, stopped-pipe law,
full-body movement, or HUL-P1-or-later validation. The current packet contains
targets and measurement templates only; fields marked `TBD` or
`measurement_required` must stay empty until bench evidence exists.

## P0 Reed Coupon (HUL-P0)

1. Source and document the reed candidate in `p0-reed-coupon-log.csv` with
   a traceable `coupon_id`.
2. Deburr any sharp edge at the reed tongue and frame edge before pressure
   checks.
3. Verify mechanical retention (plate, frame, and clip or glue) in the same log.
4. Measure reed-alone pitch and note stable tuning range in `reed_alone_pitch_hz`.
5. Capture onset-pressure sweep with a controlled source.
6. Capture pull-down test for the target pipe note, using an explicit test method.
7. If leakage-like behavior is observed while the plate is retained, label it in
   `notes` and keep `status=measurement-required`.

## P1 Single-Melody-Pipe Control (HUL-P1)

1. Select exactly one P0 source for traceability.
2. Copy the `coupon_id` into `p1-single-melody-pipe-control-log.csv`.
3. Plan chamber sketch assumptions in `windchest-geometry-plan.csv` before
   interpreting coupled pitch.
4. Build only the controlled melody pipe setup (no full gourd/three-pipe body).
5. Capture coupled pitch, blow/draw behavior, leak test method, and leak source
   separation before moving to any full-body planning claim.
6. Only promote from P1 once one linked trial passes `safety-gates.csv`, has
   measured pitch/onset/leak evidence, and closes the relevant rows in
   `validation-loop.csv`.

## Current Authority Boundary

- `family-spec.csv` remains a planning table with
  `acoustic_law=unknown_requires_measurement` for hulusi rows until HUL-P0 and
  HUL-P1 measurements exist.
- `p0-reed-coupon-log.csv` and `p1-single-melody-pipe-control-log.csv` are
  templates. They do not contain measured pull-down, onset, blow/draw, or
  coupled-pitch results yet.
- `validation.csv` may name target notes and frequencies, but blank measured
  columns are intentional and must not be interpreted as passes.
- Drawings, concept images, workbook formulas, and OpenSCAD geometry are
  packet context only until measurement rows link them to physical evidence.

## Stop Conditions

- Any sharp edge or unstable plate retention before safe-pressure checks.
- Unidentified leak that cannot be separated from reed instability.
- P1 trial attempted without passing linked P0 safety checks.
- `safe_pressure_limit_pa` missing at P0 or P1.

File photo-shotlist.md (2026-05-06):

# Hulusi — Photography Shot List

> *v4 deliverable. The shot list for the build-log site, capstone deck, and visual BOM. Capture each shot as the build progresses; replace concept renders with shop photos as soon as they exist.*

> Camera: phone is fine; tripod + soft window light is better.
> Format: shoot RAW + JPG; landscape unless noted; 4:3 or 3:2 ratio.
> Background: shop neutral OR clean white seamless OR walnut-board pad.

---

## Hero shots (recruiter-grade)

### S01 — Hero, F-key full instrument, 3/4 view
- HUL-P2 finished and tuned.
- Light: soft, single-source, slightly above and right.
- Background: walnut-board pad with subtle wood grain.
- Frame: full instrument with 10% padding all sides; tassel visible.
- Use: README hero image, capstone deck title slide, site index hero.

### S02 — Family overview, all 5 keys laid out
- All 5 instruments (B♭, C, D, F, G) lined up horizontally on neutral background, longest left.
- Top-down, perfect alignment along gourd center axis.
- Use: README family table, capstone deck "family targets" slide, site family page.

### S03 — F-key playing portrait
- Player holding instrument in playing position, 3/4 view from front.
- Hands on melody pipe, drone pipes visible.
- Use: capstone deck "ergonomics" slide.

---

## Process shots (build-log narrative)

### S04 — Pakkawood blanks pre-bore
- Three 1 in OD round dowels stacked on shop bench; blank label tags visible.
- Caption: "Cut to Pipes!B15:D15 from Master_Inputs."
- Use: site build-log step 1.

### S05 — ShopBot CNC boring melody pipe
- Action shot during deep-bore peck cycle; shavings visible.
- Show clamping fixture and ShopBot bed.
- Use: site build-log step 2, capstone deck "manufacturing" slide.

### S06 — Walnut gourd halves on lathe
- One half on the lathe with Forstner bit advancing; second half resting alongside.
- Show grain pattern in the cut.
- Use: site build-log step 4, manufacturing slide.

### S07 — Brass shim sheet on Epilog laser bed
- Sheet on bed mid-cut; tongues visible in pattern.
- Show DXF file projected on laser monitor in background.
- Use: site build-log step 6.

### S08 — Reed assembly close-up (10× macro)
- Single completed reed: brass tongue + frame plate + glue line + slot.
- Macro lens or phone macro mode.
- Caption: "0.798 in × 0.157 in × 0.008 in brass tongue."
- Use: visual-BOM, capstone deck reed-detail slide.

### S09 — Beeswax + rosin double-boiler in action
- Shop process shot; thermometer visible; mixing stick.
- Use: site build-log step 9.

### S10 — All three reeds installed in pipes (top-down)
- Looking down into pipe tops with reed assemblies in place.
- Show wax fillet at each frame-plate joint.
- Use: visual-BOM "subassemblies" panel.

### S11 — Gourd-to-pipes joint detail
- Side view of gourd belly with three pipe tops emerging; brass binding ring (if used).
- Use: drawing-brief.md HUL-DRW-001 photo placeholder.

### S12 — Drone 2 waxable foot plug
- Macro shot of the wax plug at drone 2 foot.
- Player's fingernail in frame for scale.
- Use: capstone deck "playing techniques" slide, site step 11.

---

## Reference shots (for measurement and re-derivation)

### S13 — Caliper measurement of finger-hole positions
- Calipers on melody pipe; tape measure or rule for absolute distances.
- Each hole measured against `Holes!E:E`.
- Use: validation.csv reference.

### S14 — Tuner readout for each pipe note
- Phone tuner (Cleartune) showing measured Hz.
- One photo per condition (all-closed + 7 hole-open + 2 drones).
- Use: validation.csv photo evidence.

---

## Capture cadence

| Stage | Shots to capture |
|---|---|
| HUL-P0 reed coupon | S08 |
| HUL-P1 single melody pipe | S04, S05, S07, S08, S13, S14 |
| HUL-P2 full F-key build | S01, S03, S06, S09, S10, S11, S14 |
| HUL-P3 waxable Drone 2 | S12 |
| HUL-P4 family scaling | S02 |

---

## Style notes

- Phone is fine; tripod for product shots, handheld OK for process shots.
- Soft natural light (north window) preferred over flash.
- Walnut tone is warm — don't crush blacks; preserve grain detail.
- Brass should hold highlight without burning; underexpose by 1/3 stop if needed.
- Avoid logos, brand names, or messy backgrounds in any product shot.
- All photos: shoot 5–10 takes, pick best in post.

## File naming

`hulusi_<stage>_<shot-id>_<short-description>.jpg`

Examples:
- `hulusi_p2_s01_hero-3q.jpg`
- `hulusi_p1_s05_shopbot-bore.jpg`
- `hulusi_p2_s10_reeds-installed-topdown.jpg`

Save to `images/` (replacing concept-render placeholders) and `site/photos/` (web-resized 1600px max).

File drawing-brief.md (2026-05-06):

# Hulusi Drawing Brief

## Required Views

- **Front view** with overall height, gourd belly OD, mouthpiece position, and three pipe outlets at gourd base.
- **Side view** showing pipe-axis angles (melody centered, drones at ±30°), gourd profile, and finger-hole face on melody pipe.
- **Top view** showing mouthpiece end, gourd-neck collar, and visible binding ring (if used).
- **Bottom view** showing pipe-foot openings, side-by-side, with foot diameter labels.
- **Section view through gourd centerline** — reveals wind chest volume, three pipe sockets, mouthpiece bore, and reed assembly clearances.
- **Reed-slot detail (×4 enlargement)** — tongue thickness, slot width, frame plate, mounting glue line, beeswax fillet.
- **Family-scale view** — silhouettes of B♭ / C / D / F / G with dimensional labels driven by `Family` sheet.

## Critical Dimensions

| Dimension | Source | Tolerance intent |
|---|---|---|
| Pipe total cut length (×3) | `Pipes!B15:D15` (named globals) | Tuning critical (±0.010 in) |
| Pipe bore ID | `mel_bore_ID`, `dr1_bore_ID`, `dr2_bore_ID` | Tuning critical (±0.005 in) |
| Finger hole positions | `Holes!E6:E12` | Tuning critical (±0.010 in) |
| Finger hole diameter | `mel_hole_dia` | Tuning + ergonomics (±0.005 in) |
| Reed tongue length (×3) | `Pipes!B19:D19` | Tuning critical (±0.003 in) |
| Reed slot width | `Pipes!B21:D21` | Reed seal critical (±0.002 in) |
| Reed tongue thickness | `reed_thickness` | Pitch + voice (sheet-stock tolerance) |
| Gourd belly OD | `gourd_belly_OD` | Cosmetic / ergonomic |
| Gourd internal volume | `gourd_volume_in3` | Pressure stability (±5 in³ acceptable) |
| Pipe-socket bore | 1.000 in (per HUL-CUT-003) | Air seal (±0.005 in for press-fit) |
| Mouthpiece bore | `gourd_neck_OD` | Air seal |

## Notes For CAD

- Use a SolidWorks design table linked to `hulusi-design-table.xlsx`. Global-variable names must match the `Master_Inputs!C` column **exactly** (e.g. `c_speed`, `mel_bore_ID`, `dr1_target_offset`).
- Parametrize the family configuration as a single `key_midi` configuration variable; SW should regenerate every dimension when switched between B♭/C/D/F/G.
- Keep finger-hole positions as a feature *array* indexed off the pipe foot, not absolute Y coordinates — this matches the `Holes!E:E` formula and avoids drift if `mel_reed_pad` changes.
- The reed assembly is a separate sub-assembly (`reed-assembly.SLDASM`) so the same model serves all three pipes by configuration.
- **`cad/hulusi-design-table.txt`** is the SW global-var parity reference — keep it up to date with the Excel file.
- The waxable Drone 2 foot plug is **not** parametrically modelled — it's a hand-shaped feature added after first acoustic test.
- For drawings export: use SVG for `drawings/` repo files, and DXF for laser-cuttable parts under `cnc/`.

## Drawing Sheet Layout

| Sheet | Title | Views | Scale |
|---|---|---|---|
| HUL-DRW-001 | Gourd Wind Chest | Front, side, section, mold-split | 1:1 |
| HUL-DRW-002 | Tube Set + Holes | Three tubes side-by-side, hole detail, foot detail | 1:1 |
| HUL-DRW-003 | Reed Assembly | Reed plate, tongue, slot, mounted view | 4:1 |
| HUL-DRW-004 | Sealant Application | Wax fillet sections at gourd-pipe + reed-frame | 2:1 |
| HUL-DRW-005 | Mouthpiece Insert | Lathe profile + bore section | 2:1 |
| HUL-DRW-006 | Family Scale | B♭/C/D/F/G silhouettes with dim table | 1:2 |

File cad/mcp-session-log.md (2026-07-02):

# MCP Session Log

No MCP-generated V5 artifacts were produced for this Round 4 migration.

The current hulusi packet contains a workbook, OpenSCAD starter, SVG previews,
concept images, print/site review surfaces, and empirical-loop templates. It
does not contain production STEP/STL/DXF/G-code exports, measured HUL-P0/HUL-P1
prototype data, or runtime evidence that would justify L3/build-ready claims.

| session_id | tool | input_authority | outputs | role | authority_result | review_status | notes |
| --- | --- | --- | --- | --- | --- | --- | --- |
| 2026-05-30-r4-ben-local | none | `README.md`; `design.md`; `capstone-manifest.json`; `validation-loop.csv`; `family-spec.csv`; `v4-audit.md`; `cad/hulusi-design-table.txt` | `README.md`; `visual-output-register.csv`; `cad/mcp-session-log.md` | v5_migration_inventory | reference_only | self_checked | Local text/CSV migration only. `git pull --ff-only origin main` was run first and reported already up to date. qmd CLI search found the catalog reconciliation note for hulusi; qmd query hung and was stopped. No GitHub, push, MCP, CAD, Blender, Illustrator, Photoshop, OpenSCAD runtime, SolidWorks, or Wolfram runtime session was run. |
| future-openscad-review | OpenSCAD or CAD review tool | `hulusi-design-table.xlsx`; `family-spec.csv`; `cad/hulusi_master.scad` | `cad/*.stl`; `drawings/*.dxf`; review screenshots or exported drawings | cad_authoring | pending_measurement | unreviewed | Planned only. Add a real session row before claiming generated geometry, STL, or DXF authority. |
| future-reed-dxf-export | OpenSCAD, CAD/CAM, or laser-vector tool | `hulusi-design-table.xlsx`; `cad/hulusi_master.scad`; measured HUL-P0 evidence | `cnc/reed-tongue.dxf`; `cnc/reed-frame.dxf` | dxf_export | pending_measurement | unreviewed | Planned only. Current DXF paths are absent and must remain blocked until generated and reviewed against reed coupon measurements. |
| future-visual-refresh | image-generation, Blender, Illustrator, Photoshop, or camera workflow | `photo-shotlist.md`; prototype/shop photos; `images/hero-concept.svg` | `images/hero-*`; `images/family-*`; updated site images | concept_render_or_photo_refine | concept_only | unreviewed | Planned only. Generated images remain non-dimensional; shop photos become reference evidence only when tied to build records. |
| fable-v5-refresh-2026-07-01 | claude-code (Fable 5) | README.md (status-line honesty per hulusi-bawu stopped-pipe free-reed guidance) | README.md | packet_refresh | reference_only | self_checked | Corrected README status line from "L2 V5 build-packet candidate" to "L1 concept packet": every acoustic-law row in family-spec.csv/p0-reed-coupon-log.csv/p1-single-melody-pipe-control-log.csv is still unknown_requires_measurement, which per the skill's hulusi/bawu reference means the packet stays L1_packet-equivalent until HUL-P0/HUL-P1 bench data exists. No dimension changes. |
| fable-v5-refresh-2026-07-01 | claude-code (Fable 5) + OpenSCAD CLI | hulusi-design-table.xlsx, family-spec.csv | cad/hulusi_master.scad | cad_authoring | pending_measurement | self_checked | Existing master kept as-is (no rewrite). openscad render check: pass (openscad -o STL, exit 0). |
| fable-v5-refresh-2026-07-01 | claude-code (Fable 5) + generate_wolfram_packet.py | hulusi-design-table.xlsx, family-spec.csv, validation.csv | wolfram/hulusi-wolfram-model.wl | analysis_source | derived_preview | unreviewed | Generated via $SKILL/generate_wolfram_packet.py (not executed — no --execute passed); renamed from instrument-model.wl; source-only L2 evidence, distinct from existing hulusi-starter.wl. |

## Promotion Notes

- `visual-output-register.csv` is the V5 authority map for this repo.
- `pending_measurement` rows block L3 promotion until HUL-P0 reed coupon and
  HUL-P1 single-pipe evidence are recorded and reviewed.
- Production CAD, DXF, STEP, STL, and G-code remain deferred until measured
  prototype data supports them.

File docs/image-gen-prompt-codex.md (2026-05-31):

# Image Generation Prompt

Concept visualization only. Do not treat generated images as dimensional, tuning, CAD, DXF, or fabrication authority.

## Hero Prompt

Photorealistic studio product photograph of a finished wooden hulusi concept: lathe-turned walnut gourd-shaped wind chest, three pakkawood pipes inserted through the base, center melody pipe with seven finger holes, two outer drone pipes, small brass free-reed plates partly visible at the pipe tops, wax and rosin seals at the sockets, smooth warm finish. Clean studio background, soft directional studio lighting, three-quarter product-photography angle, about a 50mm lens, high detail, photorealistic.

## In-Context Prompt

Photorealistic scene of the hulusi staged in a maker studio with brass reed coupons, a single-pipe control tube, beeswax, a tuner, and small files on the bench. Natural light, respectful cultural framing, no costume, the instrument reads as a wooden engineering prototype inspired by the Dai hulusi lineage with measurement-first reed testing.

## Detail/Macro Prompt

Macro close-up of the hulusi reed and gourd socket area: brass free reed mounted on a small plate, wax-sealed into a pakkawood pipe entering the walnut gourd wind chest, clean finger-hole edges on the melody pipe, subtle file marks and wax texture, photorealistic high detail.

## Negative / Avoid

Avoid logos, watermarks, readable text, bamboo-only assumptions, impossible reed plates, extra pipes, fake cultural decoration, distorted hands, and images that imply measured CAD authority.

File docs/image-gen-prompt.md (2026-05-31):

# Image-Gen Prompts

Concept image only; not fabrication authority. Do not include cut-ready dimensions, hole locations, reed slot widths, tuning numbers, or toolpaths.

## Hero Prompt

Photorealistic 3/4 product photograph of a finished wooden hulusi, the Chinese cucurbit free-reed flute reimagined in turned hardwood: a rounded lathe-turned walnut gourd-shaped wind chest with a slender turned neck rising to a mouthpiece at the top, and three slim cylindrical pipes inserted into the base of the gourd belly and descending parallel below it — a center melody pipe carrying a face row of finger holes flanked by two drone pipes splayed slightly outward, all three pipes in warm pakkawood with a satin oil finish, the brass free-reed mounts implied at each pipe top where it enters the gourd, beeswax-and-rosin fillets sealing the gourd-to-pipe joints, a small decorative tassel hanging from the neck, hand-playable scale cues, walnut grain and brushed-brass accents catching soft directional studio light, clean neutral studio background, 3/4 product-photography angle, ~50mm lens, high detail, photorealistic, no text labels.

## In-Context Prompt

Photorealistic image of the wooden hulusi staged on a quiet instrument-maker's bench on a warm walnut-board pad, natural north-window light, a musician's hands cradling the turned gourd wind chest with the fingers resting along the finger holes of the center melody pipe while the two drone pipes hang free, the mouthpiece raised toward the player's lips as if mid-phrase, a few brass reed coupons and a small needle file nearby for storytelling, warm workshop atmosphere, the tassel swaying at the neck, realistic walnut and pakkawood materials, shallow depth of field, concept visualization only.

## Detail Prompt

Photorealistic macro close-up of the signature mechanism: a single brass free reed seated in its frame plate at the top of a pakkawood pipe where it enters the turned walnut gourd, the thin brass tongue resting in its frame slot ready to vibrate against the airstream, a clean beeswax-and-rosin fillet sealing the frame plate into the pipe top and the pipe into the gourd socket, brushed-brass texture against warm satin wood grain, soft raking light revealing the springy edge of the reed tongue and the wax meniscus, shallow depth of field, high detail, no measurements.

## Negative / Avoid

No text, logos, watermarks, fake maker marks, or brand names; no dimension callouts or cut diagrams; no impossible mechanisms, no extra or fused pipes, no floating reeds; anatomically plausible hands if a player is shown.

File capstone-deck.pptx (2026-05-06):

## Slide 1

Hulusi (葫芦丝)

Wooden Cucurbit Free-Reed Flute Family

B♭ · C · D · F · G — five keys, one parametric workbook

HUL-001 · v4.1 instrument-maker scaffold · capstone deck

Stopped-pipe + free-reed acoustic model · 33 named globals · SolidWorks parity

github.com/tonykoop/hulusi · Tony Koop · Maker Nexus South Bay

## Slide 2

What this is

Engineering documentation for a 5-key family of wooden hulusi — the Chinese cucurbit free-reed flute.

First prototype: F-key (modern factory standard, all-closed = F4 = 349 Hz). Family scales from there.

Hulusi (葫芦丝) family · v4.1 build packet · 2026-05-05

Parametric design table

33 named global variables in Master_Inputs drive 6 derived sheets. SolidWorks design-table parity matches names exactly. 113 formulas, 0 errors.

Complete v4 build packet

BOM · sourcing · cut-list · validation · assembly manual · drawing brief · risks (red-team) · family-spec · photo shotlist · supplier RFQ.

Recruiter-grade artifacts

12-slide capstone deck · printable shop PDF · self-contained build-log site · concept renders that step aside for shop photos.

1

2

3

2 / 12

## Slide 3

Physics

Three independent stopped-pipe + free-reed systems sharing a wind chest.

All three live in Master_Inputs as named global formulas — change c_speed once, all 5 family rows update.

Hulusi (葫芦丝) family · v4.1 build packet · 2026-05-05

Stopped pipe

f = c / (4 · L_eff)

Each tube acts as a stopped pipe — closed at the reed, open at the foot.

L_eff = L_acoustic + 0.6·r_bore

End correction at the open foot only.

Default c_speed = 13,552 in/s @ 68°F.

Free reed (cantilever)

f_reed = K · t / L²

Brass C26000 tongue clamped at root, free at tip; oscillates against frame slot.

K_imperial ≈ 27,300

Tongue cut sharp by pull_down_cents (default −30¢). Tube pulls reed down to its resonance.

Finger holes

d = L · (f₀ / f_n)

Each opened hole shortens the effective length per the simple shortening rule.

Default offsets: 2 4 5 7 9 11 12

Western diatonic; traditional Chinese tuning reachable by editing semitone column.

3 / 12

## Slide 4

File map

v4.1 Mode A (single-instrument repo at root) — 24 deliverable files plus images.

Hulusi (葫芦丝) family · v4.1 build packet · 2026-05-05

Top-level docs

Parametric design

README.md

design.md

v4 hero + status table

physics + lineage + ladder

hulusi-design-table.xlsx

family-spec.csv

Master_Inputs + 6 sheets

5 keys, one row each

risks.md

LICENSE

red-team, 5 categories × tests

MIT

cad/hulusi_master.scad

cad/hulusi-design-table.txt

OpenSCAD parametric

SW global-var parity

v4-audit.md

audit trail vs v4 spec

wolfram-starter.wl

physics sanity-check

Build packet

Visual + recruiter

bom.csv

15 line items

drawings/hulusi-{Bb..G}.svg

5 per-key dimensioned

sourcing.csv

cut-list.csv

supplier candidates

12 cuts + family scaling

drawings/hulusi-section.svg

drawings/reed-detail.svg

centerline section

reed slot 4×

validation.csv

assembly-manual.md

target/measured/cents-error

14-step shop sequence

photo-shotlist.md

site/index.html

14 build-log shots

build-log static site

supplier-rfq.md

copy-paste RFQ

capstone-deck.pptx + print-packet.pdf

this deck + shop PDF

4 / 12

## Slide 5

Master_Inputs — single source of truth

33 named globals · blue inputs · every other cell is a formula · names match SolidWorks 1:1.

Master_Inputs

ACOUSTIC CONSTANTS

KEY (selectable)

MELODY PIPE (7 holes)

REED (brass C26000)

EMPIRICAL CORRECTIONS

Hulusi (葫芦丝) family · v4.1 build packet · 2026-05-05

33

named global variables

shared with SolidWorks

Speed of sound (in/s, 68°F)

13552

c_speed

Selected key MIDI

Tonic frequency (derived)

65

349.23

key_midi

f_tonic

113

live formulas across

6 derived sheets

Bore ID (in)

0.500

mel_bore_ID

Hole diameter (in)

0.275

mel_hole_dia

0

formula errors after

LibreOffice recalc

Shim thickness (in)

K constant (imperial)

0.008

27300

reed_thickness

reed_K_imperial

Reed pull-down (¢)

−30

pull_down_cents

Sister: cad/hulusi-design-table.txt — SW parity reference.

Pipe correction (%)

0.0

correction_pct

5 / 12

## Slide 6

Family — five keys, one workbook

Change key_midi once. Family sheet recomputes mel/dr1/dr2 lengths and reed-tongue lengths for all 5 keys.

★ F-key = HUL-P2 prototype 1 (in flight). All other keys deferred until F-key voicing locks.

Hulusi (葫芦丝) family · v4.1 build packet · 2026-05-05

Model

HUL-B♭

Key

B♭

Tonic Hz

175 Hz (F3)

Mel L

14.89 in

Dr1 (5th) L

10.05 in

Dr2 (oct) L

7.62 in

Reed L mel

0.977 in

Use

low / warm voice

HUL-C

C

196 Hz (G3)

13.30 in

8.99 in

6.82 in

0.922 in

vocal / intermediate

HUL-D

D

220 Hz (A3)

11.89 in

8.05 in

6.12 in

0.871 in

folk / dance pieces

HUL-F ★

F

262 Hz (C4)

10.05 in

6.82 in

5.20 in

0.798 in

STANDARD — prototype 1

HUL-G

G

294 Hz (D4)

8.99 in

6.12 in

4.67 in

0.753 in

bright / festive

B♭

14.9″

C

13.3″

D

11.9″

F ★

10.1″

G

9.0″

6 / 12

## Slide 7

Drawings & CAD

Per-family-member dimensioned SVGs (B♭/C/D/F/G) plus section, family-scale, reed-detail.

CAD pipeline: Master_Inputs → SolidWorks global vars → parametric model → SVG drawings → ShopBot/laser/lathe

OpenSCAD master at cad/hulusi_master.scad mirrors the SW parametric structure for hobbyist build path.

Hulusi (葫芦丝) family · v4.1 build packet · 2026-05-05

Centerline section

Gourd + 3 pipes + reed slot. Critical wall thickness, bore ID, pipe-axis angles.

Family scale

All 5 keys side-by-side at 1:18 px scale. Dimension labels per key from family-spec.csv.

Reed slot detail (4×)

Tongue, frame plate, slot, glue line, wax fillet. Cantilever model with K = 27,300.

7 / 12

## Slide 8

BOM & sourcing

15 line items per F-key build · ~$80–100 in materials · all parts sourced from named suppliers.

Substitution rules in sourcing.csv. Family scaling adds ~$70/key in additional wood + brass beyond the F-key build.

Hulusi (葫芦丝) family · v4.1 build packet · 2026-05-05

Walnut gourd blank (1) · Pakkawood tubes ×3

Shim 0.008″ × 1 sheet · Plate 0.040″ × 1 sheet

Per-build cost

$95

median F-key build

Wood

$30–45

Brass

$25–35

Beeswax (food grade) · Pine rosin (violin)

Sealant

$15–25

Boxwood mouthpiece · Brass binding ring

Hardware

$10–25

Reed needle-file set · (one-time, reusable)

Tooling

$15–25

Tuner / mic · (smartphone OK)

Test

$0–30

Suppliers (sourcing.csv)

• Cousineau Wood Products

• Bell Forest Products

• McMaster-Carr

• Stewart-MacDonald

• Frontier Natural / local

8 / 12

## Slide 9

Build workflow

14 shop steps. Prototype ladder runs P0 → P4 across 4–6 weeks of evening builds.

Reed coupon

validate brass-cut + slot fit

Single melody pipe

validate stopped-pipe + holes

Full F-key hulusi

hit family target (prototype 1)

Waxable Drone 2

removable-wax drone control

Family scaling

B♭/C/D/G additional builds

Full 14-step shop sequence in assembly-manual.md. Each step has failure-mode notes.

Hulusi (葫芦丝) family · v4.1 build packet · 2026-05-05

P0

1 evening

P1

1 weekend

P2

2 weekends

P3

1 evening

P4

ongoing

9 / 12

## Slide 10

Validation & empirical loop

Two correction knobs — pull_down_cents (per-reed) and correction_pct (global pipe scale) — close the loop.

Each new measurement updates the next build's targets — eventually every key prints to ±15¢ predicted.

Hulusi (葫芦丝) family · v4.1 build packet · 2026-05-05

Predict

Master_Inputs
formulas

Build

ShopBot + lathe
+ Epilog

Measure

validation.csv
tuner Hz

Correct

pull_down_cents
correction_pct

10 / 12

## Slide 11

Open risks (red team)

18 tracked risks across 5 categories. Every risk has a verification test attached.

A1 — Reed pull-down assumption

−30¢ default may be wrong by ±20¢. Whole reed family cuts to wrong target.

✓ Test: HUL-P0 measured pull-down vs predicted.

S3 — Gourd glue-line failure

Two-half hollow gourd: humidity + pressure stresses can pop the joint.

✓ Test: vacuum pressure-test at 30/60/90 days.

S1 — Pakkawood splits during boring

Resin can soften, gum the bit, or split along grain.

✓ Test: 3 consecutive bores complete with no splits.

E1 — Hand-fit ergonomics

F-key hole span (3.7″) may not fit small hands.

✓ Test: 3 players, large/avg/small hand, scale played without strain.

Full risk register at risks.md — 18 entries · 5 categories · acoustic, structural, ergonomic, supply, fit/finish.

Hulusi (葫芦丝) family · v4.1 build packet · 2026-05-05

HIGH

HIGH

MED

MED

11 / 12

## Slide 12

Next actions

Documentation complete. The HUL-P0 reed coupon is the first physical step.

HUL-P0 reed coupon

Cut 3 brass tongues on Epilog. Sound off-pipe; measure free frequency.

→ Validates A1 (reed pull-down) + A2 (K constant).

HUL-P1 melody pipe

Bore one pakkawood tube, drill 7 holes, mount reed. Validate stopped-pipe model.

→ Validates S1 (boring), full hole layout.

HUL-P2 full F-key build

Lathe gourd, assemble three pipes, full acoustic test. Hit family target.

→ Validates S3 (gourd glue), full system.

Family scaling

Once F-key voicing locks, scale to B♭/C/D/G using same workflow.

→ Documents per-key calibration in validation.csv.

github.com/tonykoop/hulusi · v4.1 instrument-maker scaffold · ready for HUL-P0

This week

Next week

Month 2

Month 3+

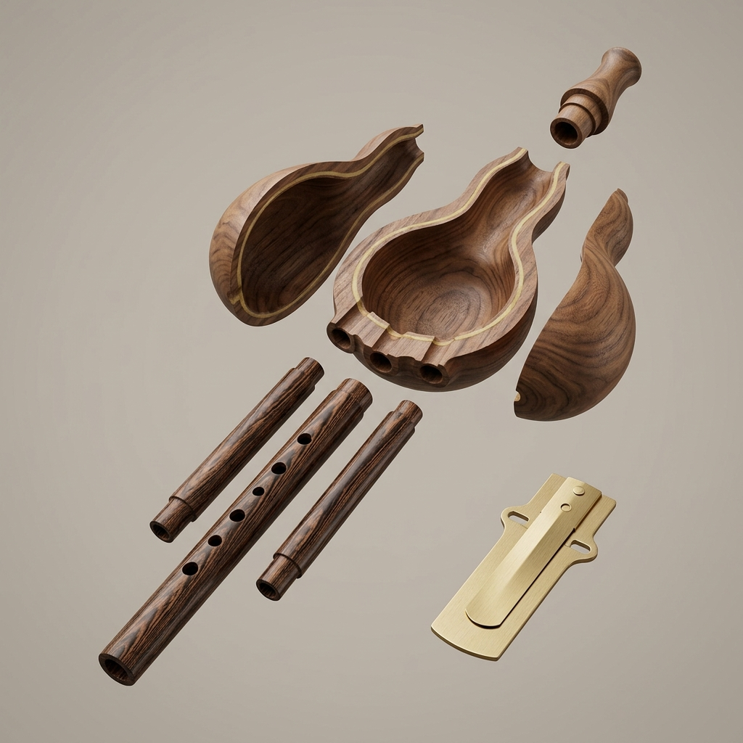
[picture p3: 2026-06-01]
images/exploded-diagram.png

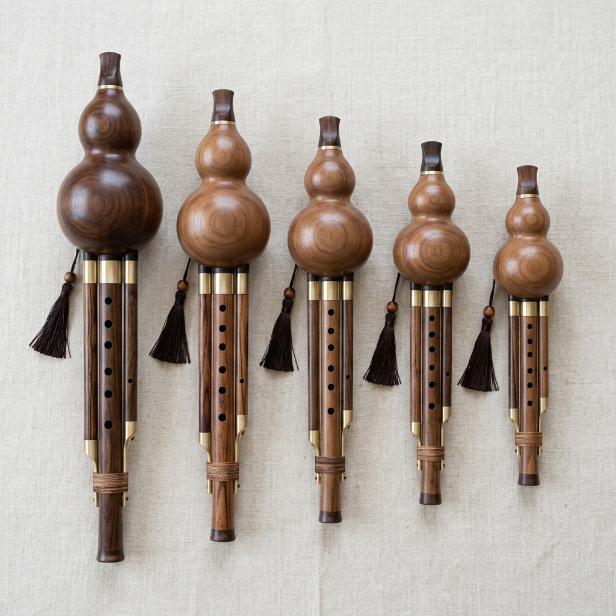
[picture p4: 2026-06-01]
images/family-group.png

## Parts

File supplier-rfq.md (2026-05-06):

# Hulusi — Supplier RFQ Template

> *Copy-paste starter for emailing suppliers.  Replace `[bracketed]` placeholders before sending.*

---

**Subject:** RFQ — Materials for hulusi (free-reed wind instrument) prototype build, 5-key family

Hi [supplier name],

I'm building a small family of wooden hulusi (Chinese cucurbit free-reed flutes) and would like a quote on the following materials. The five keys (B♭ / C / D / F / G) share the same materials list with quantity scaled per key. Please quote per the spec list below; substitutions noted are acceptable if the primary spec is unavailable.

| # | Item | Spec | Qty (one F-key build) | Qty (full 5-key family) | Acceptable substitution |
|---|---|---|---:|---:|---|
| 1 | Pakkawood round dowel | 1.0 in OD, 18 in length, straight grain, kiln-dried | 3 | 15 | Hard maple round dowel, dymondwood |
| 2 | Brass shim sheet (C26000 cartridge) | 0.008 in × 6 in × 12 in | 1 sheet | 1 sheet | Phosphor bronze 0.008 in (slight tone change) |
| 3 | Brass plate (C26000) | 0.040 in × 6 in × 12 in | 1 sheet | 1 sheet | Aluminum 6061 0.040 in (prototyping only) |
| 4 | Walnut bowl/turning blank | 5 in OD × 8 in L, kiln-dried | 1 | 5 | Cherry, hard maple, padauk |
| 5 | Beeswax (food grade, yellow) | 1 lb block | 1 | 1 | White beeswax (avoid paraffin) |
| 6 | Pine rosin (violin grade) | 8 oz | 1 | 1 | Commercial pine rosin (not bowmaker's) |
| 7 | Boxwood or buffalo horn rod | 0.5 in OD × 2 in L | 1 | 5 | European boxwood preferred |

I'd appreciate:

1. Per-unit and bulk pricing for each line.
2. Lead time and shipping estimate (US zip [zip]).
3. Whether you can hold stock for 30 days while I confirm the build schedule.

Thanks for your time. Happy to share the build documentation if it's useful — this is part of an open-source instrument-design project ([github.com/tonykoop/hulusi](https://github.com/tonykoop/hulusi)).

Best,
Tony Koop
tonykoop@gmail.com

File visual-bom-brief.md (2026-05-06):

# Hulusi Visual BOM Brief

## Goal

One-page visual BOM showing the gourd wind chest, three pipes, three brass reed assemblies, mouthpiece, and the wax/rosin sealant — recruiter-facing artifact that makes the parametric build legible at a glance.

## Layout

- **Header**: "Hulusi (葫芦丝) — Wooden Cucurbit Free-Reed Flute Family"
- **Hero image**: F-key (HUL-P2) full instrument render OR finished prototype photo
- **Family strip**: B♭ / C / D / F / G silhouettes with target tonic labels (driven by `Family` sheet)
- **Exploded view**: gourd halves split, three pipes pulled out, reed assembly enlarged ×4, mouthpiece detached
- **Reed inset**: brass tongue + frame plate + slot detail with cantilever-formula callout
- **BOM table**: HUL-BOM-001 through HUL-BOM-015 with image thumbnails
- **Physics inset**: stopped-pipe formula `f = c/(4·L_eff)` and free-reed formula `f = K·t/L²`
- **Measurement inset**: tonic Hz, drone offsets, reed pull-down target, tube total cut lengths

## Image Requirements

Use shop photos as soon as available:

- Pakkawood tube blanks pre-bore.
- ShopBot bore in progress.
- Walnut gourd halves on the lathe.
- Brass shim sheet on Epilog laser bed.
- Reed tongue + frame plate + completed reed assembly close-up.
- Beeswax + rosin double-boiler.
- F-key full instrument hero shot (replaces concept render).
- Close-up of waxable drone 2 with player's fingernail.

Concept renders or CAD images should be marked as placeholders until shop photos exist.

## Cultural Footer

A small caption on the visual BOM should read:

> The hulusi (葫芦丝) belongs to the Dai people of Yunnan. This build uses lathe-turned hardwood in place of the traditional dried bottle gourd for repeatability, but the lineage and naming are credited.

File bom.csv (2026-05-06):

item_id | category | item | qty | spec | make_buy | estimated_cost | source_note | drawing_ref | notes
HUL-BOM-001 | Gourd | Gourd wind chest, lathe-turned | 1 | Walnut blank ~5 in OD x 8 in L (per gourd_belly_OD, gourd_height in Master_Inputs) | Make | $15-25 | Local hardwood; sub dried Lagenaria gourd if traditional build | HUL-DRW-001 | Workbook estimate not date-checked.
HUL-BOM-002 | Tube | Melody tube blank | 1 | Pakkawood, 1 in OD x 18 in L (cuts to mel total length per Pipes!B15) | Buy | $10-15 | Cousineau Wood Products / Bell Forest Products | HUL-DRW-002 | Bore on ShopBot or lathe drill jig.
HUL-BOM-003 | Tube | Drone 1 tube blank | 1 | Pakkawood, 1 in OD x 14 in L (cuts to dr1 total length per Pipes!C15) | Buy | $8-12 | Cousineau / Bell Forest | HUL-DRW-002 | Same bore + wall as melody.
HUL-BOM-004 | Tube | Drone 2 tube blank | 1 | Pakkawood, 1 in OD x 10 in L (cuts to dr2 total length per Pipes!D15) | Buy | $6-10 | Cousineau / Bell Forest | HUL-DRW-002 | Plan for waxable foot plug after first acoustic test.
HUL-BOM-005 | Reed | Brass shim stock | 1 | C26000 brass, 0.008 in x 6 in x 12 in sheet (per reed_thickness) | Buy | $15-25 | McMaster 9534K27 | HUL-DRW-003 | Yields 30+ reed blanks per sheet.
HUL-BOM-006 | Reed mount | Reed frame plates | 3 | Brass 0.040 in x 0.6 in x 1.0 in plate per pipe | Make | $5 | Laser-cut from brass shim scrap or heavier shim | HUL-DRW-003 | Slot dimensions per Pipes!B21.
HUL-BOM-007 | Sealant | Beeswax (yellow, food-grade) | 1 | 1 lb block | Buy | $8-12 | Frontier Natural Products / local beekeeper | HUL-DRW-004 | Mix with rosin for luthier's wax.
HUL-BOM-008 | Sealant | Pine rosin (for wax mix) | 1 | 8 oz | Buy | $6-10 | Luthier supply (Stewart-MacDonald) or violin shop |  | Mix 4:1 wax:rosin by mass for hulusi seal.
HUL-BOM-009 | Mouthpiece | Mouthpiece insert | 1 | Boxwood or buffalo horn, 0.5 in OD x 1.5 in L | Make | $3-8 | Lathe-turn from offcut or scrap horn | HUL-DRW-005 | Bore matched to gourd_neck_OD.
HUL-BOM-010 | Decorative | Tassel + endcap | 1 | Silk tassel, traditional Dai motif | Buy | $3-6 | Etsy / specialty supplier |  | Optional; for finished/gift-quality build.
HUL-BOM-011 | Hardware | Brass binding ring | 1 | 1.25 in ID brass ring (gourd-to-tubes joint reinforcement) | Buy | $4-8 | McMaster 9499K201 | HUL-DRW-001 | Optional reinforcement at gourd belly.
HUL-BOM-012 | Tooling | Reed file set | 1 | Fine needle-file set 6 pcs | Buy | $15-25 | Stewart-MacDonald |  | One-time tooling cost.
HUL-BOM-013 | Measurement | Tuner / mic / DAW or hand tuner | 1 | Smartphone Cleartune or chromatic tuner | Have | $0-30 | Existing | HUL-VAL-001 | Required for validation loop.
HUL-BOM-014 | Consumable | CA glue + accelerator | 1 | Medium CA + spray accelerator | Buy | $8 | Existing shop stock |  | For brass-on-brass reed-to-frame mount.
HUL-BOM-015 | Consumable | Drill bit set (brad-point) | 1 | 1/64-1/2 in brad-point bit set | Have | $0 | Existing shop stock | HUL-DRW-002 | Hole_dia (default 0.275 in = 7 mm) requires letter-N or 7 mm bit.

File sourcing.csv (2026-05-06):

item_id | item | required_spec | search_terms | supplier_candidates | date_checked | unit_price | lead_time | substitution_rule | risk_note
HUL-SRC-001 | Pakkawood tube blank | 1 in OD round dowel pakkawood, straight grain | pakkawood dowel 1 inch, pakkawood rod, dymondwood | Cousineau Wood Products / Bell Forest Products / Specialty Wood |  |  |  | Substitute hard maple or ebonized maple if pakkawood unavailable | Pakkawood is dyed and resin-stabilized; check reaction to CA glue.
HUL-SRC-002 | Brass shim 0.008 in | C26000 cartridge brass shim, 0.008 in x 6 in x 12 in | brass shim 0.008 8 mil C26000 cartridge | McMaster 9534K27 / Online Metals |  |  |  | Phosphor bronze 0.008 in acceptable; tone slightly different | Thicker shim raises reed pitch and increases blowing pressure.
HUL-SRC-003 | Walnut blank for gourd | 5 in OD x 8 in L walnut, kiln-dried | walnut bowl blank 5 inch turning | Bell Forest Products / Got Wood / WoodCraft |  |  |  | Cherry or maple acceptable; padauk for premium build | Avoid green wood; gourd will check.
HUL-SRC-004 | Beeswax (food grade) | 1 lb yellow beeswax block, food grade | beeswax block 1 lb yellow food grade | Frontier Natural / local beekeeper |  |  |  | White beeswax acceptable; avoid paraffin | Pure paraffin is too brittle and does not hold reed seal.
HUL-SRC-005 | Pine rosin | 8 oz pine rosin, violin grade | violin rosin pine 8 oz luthier | Stewart-MacDonald / luthier supply |  |  |  | Substitute commercial pine rosin (not bowmaker's) | Bowmaker's rosin is too soft for permanent seals.
HUL-SRC-006 | Mouthpiece blank | Boxwood or buffalo horn 0.5 in OD x 2 in L | boxwood dowel half inch / buffalo horn rod | Bell Forest / specialty horn supplier |  |  |  | Maple or boxwood acceptable; horn is traditional | Avoid plastic - tone and tradition.
HUL-SRC-007 | Reed file set | Fine needle-file set, 6 pcs minimum | luthier needle file set fine cut | Stewart-MacDonald |  |  |  | Diamond burr set acceptable for fine work | One-time tooling cost; survives years.
HUL-SRC-008 | Brass plate 0.040 in | C26000 brass, 0.040 in x 6 in x 12 in | brass sheet 0.040 16 gauge C26000 | McMaster / Online Metals |  |  |  | Aluminum sheet acceptable for prototyping | Aluminum plates flex more; brass preferred for production.

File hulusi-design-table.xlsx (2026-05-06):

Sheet: Master_Inputs
Hulusi (葫芦丝) — Master Inputs
Single source of truth. Every other sheet derives from named ranges below.
ACOUSTIC CONSTANTS
Speed of sound (in/s, 68°F) | 13552.000 | c_speed | imperial; for SI use 343000 mm/s
A4 reference frequency (Hz) | 440.000 | A4_ref | concert pitch
KEY (selectable — drives Family sheet)
Selected key (MIDI of all-holes-closed note) | 65.000 | key_midi | F=65 (standard prototype 1). Bb=58 C=60 D=62 G=67
Tonic frequency (derived) | 349.23 | f_tonic | all-holes-closed = tonic (modern Western convention)
GOURD WIND CHEST
Gourd internal volume (in³) | 25.000 | gourd_volume_in3 | wind chest, NOT pitch-critical; provides pressure stability
Gourd OD at neck (in) | 1.100 | gourd_neck_OD | mouthpiece coupler diameter
Gourd OD at belly (in) | 4.500 | gourd_belly_OD | max diameter, lathe-turned outer profile
Gourd height (in) | 6.500 | gourd_height | neck base to belly base
Gourd wall thickness (in) | 0.200 | gourd_wall | lathe-turned wood; affects mass + tap tone
Gourd wood species | Walnut | gourd_species | dropdown: Walnut / Maple / Cherry / Padauk / dried-gourd
MELODY PIPE (7 holes — 6 front + 1 thumb)
Melody bore ID (in) | 0.500 | mel_bore_ID | internal bore; 12.7 mm typical
Melody wall thickness (in) | 0.125 | mel_wall | tube wall; 3.2 mm typical
Finger hole diameter (in) | 0.275 | mel_hole_dia | uniform hole size; 7 mm typical
Hole count (front + thumb) | 7.000 | mel_hole_count | 6 front + 1 thumb
Reed-pad clearance (in) | 0.500 | mel_reed_pad | extra length above acoustic top for reed mounting
Melody tube wood | Pakkawood | mel_wood | dropdown: Bamboo / Pakkawood / Maple / Walnut / Padauk
DRONE 1 (fixed 5th above tonic)
Drone 1 bore ID (in) | 0.500 | dr1_bore_ID | match melody for build simplicity
Drone 1 semitone offset from tonic | 7.000 | dr1_target_offset | perfect 5th = +7 semitones
Drone 1 reed-pad clearance (in) | 0.500 | dr1_reed_pad
DRONE 2 (waxable — octave above tonic by default)
Drone 2 bore ID (in) | 0.500 | dr2_bore_ID
Drone 2 semitone offset from tonic | 12.000 | dr2_target_offset | octave = +12; some traditional Dai = -5 (4th below)
Drone 2 reed-pad clearance (in) | 0.500 | dr2_reed_pad
REED MATERIAL (free-reed cantilever)
Reed Young's modulus E (psi) | 14500000.000 | reed_E_psi | brass C26000 cartridge brass
Reed density ρ (lb/in³) | 0.307 | reed_rho | brass
Reed K constant (imperial) | 27300.000 | reed_K_imperial | K = (1.875²)/(2π)·√(E/(12·ρ))/0.0254 — verify per material
Reed shim thickness (in) | 0.008 | reed_thickness | brass shim 8 mil; 0.20 mm
Reed tongue width (in) | 0.157 | reed_tongue_w | 4 mm; affects volume not pitch
Reed slot clearance per side (in) | 0.003 | reed_slot_clear | frame slot is tongue+2*clearance wide
Reed material | Brass C26000 | reed_material | dropdown: Brass C26000 / Phosphor Bronze / Beryllium Copper
EMPIRICAL CORRECTIONS (post-build calibration)
Reed pull-down (cents, target) | -30.000 | pull_down_cents | reed cut sharp by this much; tube pulls it down to its resonance
Pipe length correction (%) | 0.000 | correction_pct | post-build: if pipes consistently flat, set negative; sharp = positive
End correction multiplier | 0.600 | end_corr_k | Levine-Schwinger ≈ 0.6 for unflanged; 0.85 flanged

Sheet: Acoustics
Hulusi — Acoustic Helpers
Stopped-pipe + free-reed model. All formulas reference Master_Inputs named globals.
STOPPED PIPE — f = c / (4 · L_eff)
Quantity | Formula / Value | Notes
Bore radius — melody (in) | 0.250 | r = ID/2
End correction — melody (in) | 0.150 | ΔL ≈ 0.6·r at open foot
Acoustic length needed for tonic (in) | 9.701 | first-order target — refine with end corr
Effective length for tonic (in) | 9.551 | physical tube length, before reed pad
Tube length, melody, total (in) | 10.051 | what the CNC sees — includes reed mount allowance
FREE REED — f_reed = K · t / L_tongue²
Reed tongue length for tonic (in) | 0.7977 | tune reed sharp by pull_down_cents so tube pulls it down
Reed natural frequency at that L (Hz) | 343.23 | should match f_tonic shifted up by pull_down_cents
CENTS-ERROR HELPER
cents_error(measured, target) | 1200·LOG2(meas/tgt) | use this in Validation sheet

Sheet: Pipes
Hulusi — Per-Pipe Geometry
Three pipes, one column each. All formulas pull from Master_Inputs.
Quantity | Melody | Drone 1 (5th) | Drone 2 (oct/wax) | Notes
Semitone offset from tonic | 0 | 7 | 12 | melody all-closed = tonic; drones fixed
MIDI note | 65 | 72 | 77
Target frequency (Hz) | 349.23 | 523.25 | 698.46 | from MIDI
Bore ID (in) | 0.500 | 0.500 | 0.500 | from Master_Inputs
End correction ΔL (in) | 0.150 | 0.150 | 0.150 | 0.6·r at open foot
Acoustic length c/(4·f) (in) | 9.701 | 6.475 | 4.851 | first-order, no end-corr
Effective length L_eff (in) | 9.551 | 6.325 | 4.701 | physical tube length
Length correction (%) | 0.0 | 0.0 | 0.0 | post-build empirical knob
Corrected tube length (in) | 9.551 | 6.325 | 4.701 | what to cut, before adding reed-pad
Reed-pad clearance (in) | 0.500 | 0.500 | 0.500 | extra above acoustic top for reed mount
TOTAL CUT LENGTH (in) | 10.051 | 6.825 | 5.201 | → goes to cut-list.csv
REED TARGETS (cantilever, brass shim)
Reed target freq (Hz, sharp by pull_down_cents) | 343.23 | 514.26 | 686.46 | tube pulls reed down to f_pipe
Reed tongue length (in) | 0.7977 | 0.6517 | 0.5641 | L = √(K·t / f)
Reed tongue width (in) | 0.157 | 0.157 | 0.157 | uniform; affects volume not pitch
Reed slot opening (in, frame) | 0.1630 | 0.1630 | 0.1630 | tongue + clearance both sides

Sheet: Holes
Hulusi — Melody Pipe Finger-Hole Layout
All-holes-closed = tonic. Default = major scale (Western convention).
Edit Semitone column for traditional Chinese tuning (e.g. all-closed = sol).
Hole # | Scale degree | Semitone | Frequency (Hz) | Dist from foot (in) | Hole Ø (in) | Notes
1 | tonic +2 (re/sol→la) | 2 | 392.00 | 8.509 | 0.275 | lowest hole — first opened
2 | tonic +4 (mi) | 4 | 440.00 | 7.581 | 0.275
3 | tonic +5 (fa) | 5 | 466.16 | 7.155 | 0.275
4 | tonic +7 (sol) | 7 | 523.25 | 6.375 | 0.275 | perfect 5th — sometimes drone-matching
5 | tonic +9 (la) | 9 | 587.33 | 5.679 | 0.275
6 | tonic +11 (ti) | 11 | 659.26 | 5.060 | 0.275
7 | tonic +12 (octave, thumb) | 12 | 698.46 | 4.776 | 0.275 | thumb hole on back
— | all closed = tonic (reference) | 0 | 349.23 | 9.551 |  | fundamental at full pipe length

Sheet: Family
Hulusi Family — Live by Key
Every dimension recalculates from Master_Inputs. Change mel_bore_ID once → all 5 keys update.
Model | Key | MIDI | Tonic Hz | Mel L (in) | Dr1 L (in) | Dr2 L (in) | Reed L mel (in) | Reed L dr1 (in) | Best for
HUL-Bb | B♭ | 58 | 233.08 | 14.89 | 10.05 | 7.62 | 0.9764 | 0.7977 | low / warm voice
HUL-C | C | 60 | 261.63 | 13.30 | 8.99 | 6.82 | 0.9216 | 0.7529 | intermediate / vocal
HUL-D | D | 62 | 293.66 | 11.89 | 8.05 | 6.12 | 0.8699 | 0.7107 | folk / dance pieces
HUL-F | F | 65 | 349.23 | 10.05 | 6.82 | 5.20 | 0.7977 | 0.6517 | STANDARD — prototype 1
HUL-G | G | 67 | 392.00 | 8.99 | 6.12 | 4.67 | 0.7529 | 0.6151 | bright / festive

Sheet: BOM
Hulusi — Bill of Materials
item_id | category | item | qty | spec | make/buy | est_cost | supplier_note | drawing_ref
HUL-BOM-001 | Gourd | Gourd wind chest, lathe-turned | 1 | Walnut blank Ø5" × 8" L (per Master_Inputs gourd_*) | Make | $15-25 | Local hardwood; or sub dried Lagenaria gourd | HUL-DRW-001
HUL-BOM-002 | Tube | Melody tube blank | 1 | Pakkawood, Ø1" × 18" L | Buy | $10-15 | Cousineau / Bell Forest | HUL-DRW-002
HUL-BOM-003 | Tube | Drone 1 tube blank | 1 | Pakkawood, Ø1" × 14" L | Buy | $8-12 | Cousineau / Bell Forest | HUL-DRW-002
HUL-BOM-004 | Tube | Drone 2 tube blank | 1 | Pakkawood, Ø1" × 10" L | Buy | $6-10 | Cousineau / Bell Forest | HUL-DRW-002
HUL-BOM-005 | Reed | Brass shim stock | 1 | C26000 brass, 0.008" × 6" × 12" sheet | Buy | $15-25 | McMaster 9534K27 | HUL-DRW-003
HUL-BOM-006 | Reed mount | Reed frame plates (3 ea) | 3 | Brass 0.040" × 0.6" × 1.0" | Make | $5 | Laser-cut from brass shim scrap | HUL-DRW-003
HUL-BOM-007 | Sealant | Beeswax (yellow, food-grade) | 1 | 1 lb block | Buy | $8-12 | Frontier Natural | HUL-DRW-004
HUL-BOM-008 | Sealant | Pine rosin (for wax mix) | 1 | 8 oz | Buy | $6-10 | Luthier supply
HUL-BOM-009 | Mouthpiece | Mouthpiece insert | 1 | Boxwood or buffalo horn, Ø0.5" × 1.5" L | Make | $3-8 | Lathe-turn from offcut | HUL-DRW-005
HUL-BOM-010 | Decorative | Tassel + endcap | 1 | Silk tassel, traditional Dai motif | Buy | $3-6 | Etsy / specialty supplier
HUL-BOM-011 | Hardware | Brass binding ring | 1 | Ø1.25" ID brass ring (gourd-to-tubes joint) | Buy | $4-8 | McMaster 9499K201 | HUL-DRW-001
HUL-BOM-012 | Tooling | Reed file set | 1 | Fine needle-file set 6 pcs | Buy | $15-25 | Stewart-MacDonald
HUL-BOM-013 | Measurement | Tuner / mic / DAW or hand tuner | 1 | Smartphone Cleartune or chromatic tuner | Have | $0-30 | Existing | HUL-VAL-001
HUL-BOM-014 | Consumable | CA glue + accelerator | 1 | Medium CA + spray accelerator | Buy | $8 | Existing shop stock

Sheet: Validation
Hulusi — Validation Log
Per-build, per-pipe target/measured/cents-error log. Feed cents-error back into correction_pct.
build_id | stage | pipe | condition | target_note | target_Hz | measured_Hz | cents_error | wax_added_g | tongue_filed_in | action | result | notes
HUL-P0 | reed-coupon | — | free | tonic+pull_down |  |  |  |  |  | file tongue |  | verify reed-cut process
HUL-P1 | single-pipe | Mel | all-closed | tonic |  |  |  |  |  | tune reed |  | F-key prototype only
HUL-P1 | single-pipe | Mel | hole-1 | tonic+2
HUL-P2 | full-build | Mel | all-closed | tonic |  |  |  |  |  |  |  | F-key full instrument
HUL-P2 | full-build | Mel | hole-7 | tonic+12
HUL-P2 | full-build | Dr1 | free | tonic+5th
HUL-P2 | full-build | Dr2 | free | tonic+oct

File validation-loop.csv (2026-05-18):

check_id | packet_artifact | readiness_before | prediction_source | target | tolerance | method | measured_result | status | next_action | evidence | source_status
HUL-VL-001 | p0-reed-coupon-log.csv:HUL-P0-F-001 | L1_packet | candidate reed stock | reed source material gap window and retention recorded | measurement_required | Inspect and document the reed coupon before pressure is applied | TBD | measurement_required | Register actual reed source dimensions fixture retention debur status and safe pressure limit | p0-reed-coupon-log.csv | substitution_candidate
HUL-VL-002 | safety-gates.csv:SAFE-001..SAFE-004 | L1_packet | P0 safety checklist | P0 handling and pressure sweep are safe to interpret | all P0 safety gates pass | Complete debur retention regulated-air and safe-pressure checks before onset readings | TBD | measurement_required | Pass SAFE-001 through SAFE-004 before recording pull-down as evidence | safety-gates.csv | n_a
HUL-VL-003 | p0-reed-coupon-log.csv:HUL-P0-F-001 | L1_packet | pull_down_cents workbook seed | reed-alone pitch onset pressure blow/draw behavior and pull-down cents captured | measurement_required | Run controlled pressure sweep with tuner and compare reed-alone Hz to coupled test fixture Hz | TBD | measurement_required | Do not update workbook pull_down_cents until at least one repeatable coupon row is measured | p0-reed-coupon-log.csv | substitution_candidate
HUL-VL-004 | p1-single-melody-pipe-control-log.csv:HUL-P1-F-001 | L1_packet | HUL-P0 coupon traceability | P1 row links to a measured P0 coupon before interpretation | linked coupon has measured P0 evidence | Copy the measured P0 coupon_id into the P1 row and verify all required P0 fields | TBD | measurement_required | Block P1 coupled-pitch claims until HUL-P0-F-001 has measured evidence | p1-single-melody-pipe-control-log.csv | n_a
HUL-VL-005 | windchest-geometry-plan.csv:HUL-WC-P1-F | L1_packet | windchest planning row | chamber volume pressure path gasket land service direction and leak method recorded | measurement_required | Fill chamber plan then run low-pressure leak separation before pitch interpretation | TBD | measurement_required | Separate chamber leak behavior from reed response before changing acoustic assumptions | windchest-geometry-plan.csv | n_a
HUL-VL-006 | p1-single-melody-pipe-control-log.csv:HUL-P1-F-001 | L1_packet | single-pipe stopped/free-reed planning model | all-closed coupled pitch onset leak status and pitch error measured | +/-25 cents after documented adjustment | Measure one linked reed on one measured pipe with tuner pressure and leak notes | TBD | measurement_required | Keep acoustic_law unknown_requires_measurement until this row has measured HUL-P1 evidence | p1-single-melody-pipe-control-log.csv | n_a
HUL-VL-007 | family-spec.csv | L1_packet | validate_acoustic_law.py | hulusi rows stay measurement_required until HUL-P0 and HUL-P1 evidence exists | validator exits with warnings only for unknown law | Run validate_acoustic_law.py family-spec.csv and record warnings as readiness gates | TBD | measurement_required | Promote individual rows only after measured coupon and pipe-control evidence supports a declared law | family-spec.csv | n_a
HUL-VL-008 | explorer.html | L1_packet | Round 30 explorer contract | explorer points reviewers to the empirical loop and does not claim measured results | manual review | Open explorer.html and verify HUL-P0/HUL-P1 logs are linked from Validation Gates | TBD | measurement_required | Keep generated and concept visuals out of fabrication authority until measurements exist | explorer.html | n_a

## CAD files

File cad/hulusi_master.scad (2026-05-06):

// =============================================================
// Hulusi (葫芦丝) — Parametric OpenSCAD Master-Shape Starter
// =============================================================
// Generated 2026-05-05 from hulusi-design-table.xlsx (v4.1).
// Units: inches. All variable names match the Master_Inputs
// named globals in the Excel design table AND the SolidWorks
// global-variable list in cad/hulusi-design-table.txt.
//
// This is a master-shape STARTER — captures gourd profile,
// three pipes with finger holes, reed slot envelopes, and
// mouthpiece. NOT final production CAD: rim radii, ergonomic
// finger comfort, and reed-frame mounting must be refined in
// SolidWorks before machining.
//
// Family: B♭ / C / D / F / G — switch via key_midi.
// =============================================================

$fn = 96;

// --------- INPUT PARAMETERS (must match Master_Inputs) ---------

// Acoustic constants
c_speed         = 13552;     // in/s @ 68°F
A4_ref          = 440;       // Hz

// Key (58=Bb, 60=C, 62=D, 65=F, 67=G)
key_midi        = 65;
f_tonic         = A4_ref * pow(2, (key_midi - 69) / 12);

// Gourd
gourd_volume_in3 = 25.0;
gourd_neck_OD    = 1.10;
gourd_belly_OD   = 4.50;
gourd_height     = 6.50;
gourd_wall       = 0.20;

// Melody pipe
mel_bore_ID      = 0.500;
mel_wall         = 0.125;
mel_hole_dia     = 0.275;
mel_hole_count   = 7;
mel_reed_pad     = 0.50;

// Drone 1 (5th)
dr1_bore_ID         = 0.500;
dr1_target_offset   = 7;
dr1_reed_pad        = 0.50;

// Drone 2 (octave / wax)
dr2_bore_ID         = 0.500;
dr2_target_offset   = 12;
dr2_reed_pad        = 0.50;

// Reed
reed_K_imperial  = 27300;
reed_thickness   = 0.008;
reed_tongue_w    = 0.157;
reed_slot_clear  = 0.003;

// Empirical
pull_down_cents  = -30;
correction_pct   = 0;
end_corr_k       = 0.6;

// ---------------------- FUNCTIONS ------------------------------

function pipe_total_length(bore, reed_pad, semitone_offset) =
    let(
        f = f_tonic * pow(2, semitone_offset / 12),
        L_acoustic = c_speed / (4 * f),
        L_eff = L_acoustic - end_corr_k * (bore / 2),
        L_corrected = L_eff * (1 + correction_pct / 100)
    )
    L_corrected + reed_pad;

function reed_tongue_length(semitone_offset) =
    let(
        f_pipe = f_tonic * pow(2, semitone_offset / 12),
        f_reed_target = f_pipe * pow(2, pull_down_cents / 1200)
    )
    sqrt(reed_K_imperial * reed_thickness / f_reed_target);

// Hole positions on melody pipe (semitones above tonic)
hole_offsets = [2, 4, 5, 7, 9, 11, 12];

function hole_dist_from_foot(semitone_offset) =
    let(
        L_eff = c_speed / (4 * f_tonic) - end_corr_k * (mel_bore_ID / 2),
        f_hole = f_tonic * pow(2, semitone_offset / 12)
    )
    L_eff * (f_tonic / f_hole);

// ---------------------- GEOMETRY -------------------------------

module gourd_outer() {
    // Egg/pot profile — narrow at neck, wide at belly.
    hull() {
        translate([0, 0, gourd_height * 0.10])
            scale([gourd_belly_OD/2, gourd_belly_OD/2, gourd_height * 0.40])
                sphere(r = 1);
        translate([0, 0, gourd_height * 0.85])
            scale([gourd_neck_OD * 0.6, gourd_neck_OD * 0.6, gourd_height * 0.18])
                sphere(r = 1);
        // Flat-ish base for stability
        translate([0, 0, 0])
            scale([gourd_belly_OD/2 * 0.85, gourd_belly_OD/2 * 0.85, gourd_height * 0.04])
                sphere(r = 1);
    }
}

module gourd_inner() {
    hull() {
        translate([0, 0, gourd_height * 0.10])
            scale([gourd_belly_OD/2 - gourd_wall,
                   gourd_belly_OD/2 - gourd_wall,
                   gourd_height * 0.40 - gourd_wall])
                sphere(r = 1);
        translate([0, 0, gourd_height * 0.85])
            scale([gourd_neck_OD * 0.6 - gourd_wall,
                   gourd_neck_OD * 0.6 - gourd_wall,
                   gourd_height * 0.18])
                sphere(r = 1);
        translate([0, 0, 0])
            scale([gourd_belly_OD/2 * 0.85 - gourd_wall,
                   gourd_belly_OD/2 * 0.85 - gourd_wall,
                   gourd_height * 0.04 - gourd_wall])
                sphere(r = 1);
    }
}

module mouthpiece_bore() {
    translate([0, 0, gourd_height * 0.95])
        cylinder(h = gourd_height * 0.20,
                 d = gourd_neck_OD * 0.70,
                 center = false);
}

module pipe_with_reed_slot(total_L, bore, semitone_offset, with_holes = false) {
    difference() {
        // outer tube
        cylinder(h = total_L, d = bore + 2 * mel_wall, center = false);
        // bore
        translate([0, 0, -0.01])
            cylinder(h = total_L + 0.02, d = bore, center = false);
        // reed slot (top)
        slot_w = reed_tongue_w + 2 * reed_slot_clear;
        slot_L = reed_tongue_length(semitone_offset) + 0.040;
        translate([0, 0, total_L - mel_reed_pad - slot_L/2])
            rotate([0, 0, 90])
                cube([slot_w, bore + 2 * mel_wall + 0.02, slot_L], center = true);
        // finger holes (only on melody)
        if (with_holes) {
            for (off = hole_offsets) {
                d = hole_dist_from_foot(off);
                translate([0, 0, d])
                    rotate([0, 90, 0])
                        cylinder(h = bore + 2 * mel_wall + 0.02,
                                 d = mel_hole_dia,
                                 center = true);
            }
        }
    }
}

module hulusi() {
    // Gourd
    difference() {
        gourd_outer();
        gourd_inner();
        mouthpiece_bore();
    }

    // Three pipes hanging off gourd base
    mel_L = pipe_total_length(mel_bore_ID, mel_reed_pad, 0);
    dr1_L = pipe_total_length(dr1_bore_ID, dr1_reed_pad, dr1_target_offset);
    dr2_L = pipe_total_length(dr2_bore_ID, dr2_reed_pad, dr2_target_offset);

    // Melody (centered, hanging down)
    translate([0, 0, -mel_L])
        pipe_with_reed_slot(mel_L, mel_bore_ID, 0, true);

    // Drone 1 (player's right, ±30°)
    translate([gourd_belly_OD * 0.30, 0, 0])
        rotate([0, 15, 0])
            translate([0, 0, -dr1_L])
                pipe_with_reed_slot(dr1_L, dr1_bore_ID, dr1_target_offset, false);

    // Drone 2 (player's left, ±30°)
    translate([-gourd_belly_OD * 0.30, 0, 0])
        rotate([0, -15, 0])
            translate([0, 0, -dr2_L])
                pipe_with_reed_slot(dr2_L, dr2_bore_ID, dr2_target_offset, false);

    // Echo computed dimensions for sanity check
    echo(str("=== Hulusi key_midi=", key_midi, " (f_tonic=", f_tonic, " Hz) ==="));
    echo(str("  mel_total_L  = ", mel_L, " in"));
    echo(str("  dr1_total_L  = ", dr1_L, " in"));
    echo(str("  dr2_total_L  = ", dr2_L, " in"));
    echo(str("  reed_L_mel   = ", reed_tongue_length(0), " in"));
    echo(str("  reed_L_dr1   = ", reed_tongue_length(dr1_target_offset), " in"));
    echo(str("  reed_L_dr2   = ", reed_tongue_length(dr2_target_offset), " in"));
    for (i = [0 : len(hole_offsets) - 1]) {
        echo(str("  hole_", i + 1, "_dist_from_foot = ",
                 hole_dist_from_foot(hole_offsets[i]), " in"));
    }
}

// ----------------------- DEFAULT PREVIEW -----------------------

hulusi();

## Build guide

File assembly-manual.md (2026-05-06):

# Hulusi Assembly Manual

## Scope

This manual covers wooden-gourd hulusi prototypes driven by `hulusi-design-table.xlsx`, starting with the F-key standard and expanding to a B♭/C/D/G family. Reeds are brass C26000 cantilever free reeds, laser-cut and hand-tuned.

## Tools

- SolidWorks (parametric model linked to the design table via global variables).
- ShopBot CNC router (or lathe drill jig) for tube boring + cutoff.
- Wood lathe (12 in+ swing) for gourd halves and mouthpiece.
- Drill press with stop block + indexing fence (for finger holes).
- Epilog laser cutter (brass-shim reed tongues + frame plates from `cnc/reed-tongue.dxf`).
- Calipers, dial indicator, square, deep-bore depth gauge.
- Reed file set (fine needle files, six-piece minimum).
- Tuner / mic / DAW for validation.
- Beeswax + rosin double-boiler for luthier's wax.
- Standard hand tools: chisel, scraper, sandpaper to 400, CA glue + accelerator.

## Process

1. **Confirm design table inputs**
   - Open `hulusi-design-table.xlsx`, set `key_midi` to target key (65 = F4 standard).
   - Verify SolidWorks design table is linked and has refreshed (`Tools → Equations → Manage`).
   - Print `Pipes` and `Holes` sheets — these are the shop reference.

2. **Cut and bore tubes (HUL-CUT-004 / 005 / 006)**
   - Cut three pakkawood tube blanks to total cut lengths from `Pipes!B15:D15`.
   - Bore 0.500 in ID through each. Verify bore concentricity with dial indicator at both ends.
   - Square both ends; mark "REED" end on each (the upper end where the brass mounts).

3. **Drill finger holes on melody pipe (HUL-CUT-007)**
   - Index off the open foot (bottom). Use stop block at each `Holes!E:E` distance.
   - **Drill undersize first** (0.250 in pilot); ream to `mel_hole_dia` only after acoustic test in step 11.
   - Holes 1-6 on front (in-line); hole 7 on back, slightly offset for thumb comfort.

4. **Lathe-turn gourd halves (HUL-CUT-001 / 002)**
   - Turn outer profile from `gourd_belly_OD` and `gourd_height` parameters.
   - Hollow each half to `gourd_volume_in3` cumulative — verify by water-fill at leather-glue stage.
   - Glue halves with hide glue (reversible) or epoxy. Clamp 24 hours.

5. **Bore pipe sockets in gourd (HUL-CUT-003)**
   - Drill three 1.0 in sockets through gourd lower half: melody centered, drones at ±30° angle on either side.
   - Socket depth = 0.50 in (matches `mel_reed_pad`); bushing inserts give the press-fit seal.
   - Test-fit each tube dry before any glue.

6. **Cut reed frame plates (HUL-CUT-008)**
   - Laser-cut brass plates (0.040 in stock) on the Epilog using `cnc/reed-frame.dxf`.
   - Slot opening per `Pipes!B21:D21` (default 0.163 in for 4 mm tongue + 0.003 clearance × 2).
   - Deburr edges with #400 sandpaper.

7. **Cut reed tongues (HUL-CUT-009)**
   - Laser-cut brass shim 0.008 in tongues using `cnc/reed-tongue.dxf`.
   - Lengths per `Pipes!B19:D19` (default F-key: melody 0.80 in, drone1 0.65 in, drone2 0.56 in).
   - Cut **3-4× spares per pipe** — reeds are consumables until voicing locked.

8. **Mount reeds on frame plates**
   - CA-glue tongue to frame plate at the *root only* (a 0.05 in glue line).
   - Center the tongue in the slot; visual gap ~0.003 in per side.
   - Sound test by blowing across the tongue — should sound a pure note within 50 ¢ of `Pipes!B18:D18` target (sharp by `pull_down_cents`).
   - File tip to raise pitch, file root to lower pitch. Work in 0.005 in increments.

9. **Mount reed assemblies onto pipes**
   - Beeswax-rosin seal between reed-plate underside and pipe top (REED-marked end).
   - Reed faces *inward* (into pipe / gourd chest). Air flow: mouthpiece → gourd → pipe top → reed → pipe → open foot.
   - Press firmly; the wax should ooze 1-2 mm at the joint, then trim flush.

10. **Press-fit pipes into gourd**
    - Wax-and-rosin seal each pipe-to-socket joint.
    - Melody centered; drone 1 (5th) on player's right; drone 2 (octave/wax) on player's left (traditional Dai layout).
    - Mouthpiece insert into gourd neck, also wax-sealed.

11. **First acoustic test — solo each pipe**
    - Cover all melody finger holes; play each note from `Holes` sheet sequentially (open hole 1, then 2, …).
    - Record measured frequency for each in `validation.csv`.
    - Drone 1 and Drone 2 produce continuous tones; record both.
    - Compute cents-error per row (formula in `Validation!H:H`).

12. **Tune by wax addition or hole reaming**
    - **Sharp by < 25 ¢**: leave alone — within tolerance.
    - **Sharp by 25-50 ¢**: ream the offending hole 0.005 in larger (raises hole pitch).
    - **Flat by 25-50 ¢**: add wax pastille to hole *edge* on the foot side (lowers hole pitch by partially closing the hole).
    - **All pipes flat by similar amount**: set `correction_pct` positive in Master_Inputs and re-cut next build's pipes. Don't re-cut current build.
    - **Reed flat (whole pipe flat regardless of holes)**: re-file reed tongue tip to raise.

13. **Drone 2 wax foot plug (HUL-P3 stage)**
    - Mix luthier's wax: 4 parts beeswax + 1 part pine rosin by mass; melt + cool to soft pastille.
    - Apply pastille at drone 2 open foot, leaving a small uncovered slot.
    - Player can scrape the wax with a fingernail mid-phrase to "open" or "close" the drone.
    - Tune the wax-covered pitch separately — typically a 4th or 5th below the open drone.

14. **Final validation**
    - Re-measure all `validation.csv` rows after a 24-hour rest (humidity stabilization).
    - Hand to second player to verify ergonomic comfort.
    - Photograph for `images/` and update README hero.

## Failure Modes To Watch

- **Reed silent or warbling**: tongue too tight in slot — file slot wider, or tongue too loose — re-cut.
- **Reed sounds but pipe doesn't speak**: gourd-to-pipe seal leak — re-wax. Or mouth-pressure too low — try harder breath.
- **One pipe overpowers the others**: reed too thin (high airflow, low impedance match) — try thicker shim. Or pipe wall too thin — sub a thicker wall blank.
- **All pipes consistently flat post-build**: set `correction_pct` positive in `Master_Inputs` for next build.
- **Hole notes uneven (some sharp, some flat)**: hole position error from off-by-one drill stop. Re-measure each hole's `dist_from_foot` against `Holes!E:E`.
- **Drone 2 wax falls off**: ratio of rosin too low (try 5:1 wax:rosin instead of 4:1) or wax not fully cooled before applying.
- **Reed cracks at root**: brass too thin or too brittle — try 0.010 in shim, or anneal the brass first (heat dull red, air-cool).

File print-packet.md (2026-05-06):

# Hulusi — Print Packet (Shop-Floor Reference)

> *Print this and take it to the bench.  It bundles the design table summary, BOM, cut list, and tuning loop into one shop-friendly document.*

---

## 1. Master_Inputs (set before any cutting)

| Variable | Default | Yours |
|---|---:|---:|
| `key_midi` | 65 (F4) | _____ |
| `mel_bore_ID` | 0.500 in | _____ |
| `mel_hole_dia` | 0.275 in | _____ |
| `dr1_target_offset` | +7 (5th) | _____ |
| `dr2_target_offset` | +12 (oct) | _____ |
| `reed_thickness` | 0.008 in | _____ |
| `reed_tongue_w` | 0.157 in | _____ |
| `pull_down_cents` | −30 ¢ | _____ |
| `correction_pct` | 0 % | _____ |

**If any value above changes, re-print this sheet — every length downstream depends on these.**

---

## 2. Cut targets (F-key default — re-derive from `Pipes` sheet for other keys)

| Part | Length | Bore | Notes |
|---|---:|---:|---|
| Melody tube | **10.05 in** | 0.500 in | + reed_pad already included |
| Drone 1 (5th) | **6.82 in** | 0.500 in | |
| Drone 2 (oct) | **5.20 in** | 0.500 in | leave foot for wax plug |
| Reed tongue mel | **0.798 in** L × 0.157 in W × 0.008 in T | — | brass C26000 |
| Reed tongue dr1 | **0.652 in** L × 0.157 in W × 0.008 in T | — | |
| Reed tongue dr2 | **0.564 in** L × 0.157 in W × 0.008 in T | — | |
| Reed slot opening | 0.163 in × tongue_L + 0.040 in | — | tongue + 0.003 in clearance / side |

---

## 3. Finger-hole positions (F-key, from foot)

| Hole | Note | Frequency | Distance from foot |
|---|---|---:|---:|
| 1 (low front) | G4 | 392.0 Hz | **8.51 in** |
| 2 | A4 | 440.0 Hz | **7.58 in** |
| 3 | A♯4 | 466.2 Hz | **7.16 in** |
| 4 | C5 | 523.3 Hz | **6.38 in** |
| 5 | D5 | 587.3 Hz | **5.68 in** |
| 6 | E5 | 659.3 Hz | **5.06 in** |
| 7 (thumb back) | F5 (octave) | 698.5 Hz | **4.78 in** |

Drill **undersize first** (0.250 in pilot). Ream to 0.275 in only after the acoustic test confirms the hole position is right.

---

## 4. Reed cutting + voicing loop

```text
                    ┌───────────────┐
                    │ Cut tongue   │
                    │ (laser DXF)   │
                    └──────┬────────┘
                           ▼
                    ┌──────────────┐
                    │ Mount on     │
                    │ frame plate  │
                    │ (CA at root) │
                    └──────┬───────┘
                           ▼
                    ┌──────────────┐
                    │ Sound test   │
                    │ off the pipe │
                    └──────┬───────┘
                           ▼
              ┌────────────┴────────────┐
              │ Pitch within ±50 ¢ of   │
              │ Pipes!B18 target?        │
              └────────────┬────────────┘
                  yes ─────│───── no
                           ▼
                    ┌──────────────┐         File tongue:
                    │ Mount on pipe│        ─ TIP to RAISE
                    │ + wax seal   │        ─ ROOT to LOWER
                    └──────┬───────┘         in 0.005 in steps
                           ▼
                    ┌──────────────┐
                    │ Test on full │
                    │ instrument   │
                    └──────┬───────┘
                           ▼
                    Record cents_error
                    in validation.csv
```

---

## 5. BOM checklist (one F-key build)

- [ ] HUL-BOM-001  Walnut gourd blank, 5 in × 8 in
- [ ] HUL-BOM-002  Pakkawood melody tube, 1 in OD × 18 in
- [ ] HUL-BOM-003  Pakkawood drone 1 tube, 1 in OD × 14 in
- [ ] HUL-BOM-004  Pakkawood drone 2 tube, 1 in OD × 10 in
- [ ] HUL-BOM-005  Brass shim 0.008 in × 6 in × 12 in
- [ ] HUL-BOM-006  Brass plate 0.040 in (frame plates × 3)
- [ ] HUL-BOM-007  Beeswax (food grade)
- [ ] HUL-BOM-008  Pine rosin
- [ ] HUL-BOM-009  Boxwood / horn mouthpiece blank
- [ ] HUL-BOM-010  Tassel (optional cosmetic)
- [ ] HUL-BOM-011  Brass binding ring (optional)
- [ ] HUL-BOM-012  Reed file set
- [ ] HUL-BOM-013  Tuner (smartphone Cleartune OK)
- [ ] HUL-BOM-014  CA glue + accelerator
- [ ] HUL-BOM-015  Brad-point drill set (need 7 mm or letter-N for 0.275 in)

---

## 6. Tuning fast-reference

| Symptom | Cause | Fix |
|---|---|---|
| Reed silent | Tongue jammed in slot | File slot or tongue 0.001 in larger |
| Reed warbles | Tongue too tight | Same — clearance issue |
| Reed pitch wrong by 20-50 ¢ | Tongue length off | File **tip** raise / **root** lower |
| Pipe doesn't speak | Air leak at gourd-pipe joint | Re-wax + rosin |
| All 7 holes flat by similar ¢ | Pipe too long globally | Set `correction_pct` positive next build |
| One hole sharp/flat (others OK) | Hole position error | Ream that hole or wax-fill |
| Drones overpowering melody | Drone reed too thin | Sub thicker shim or partially block drone foot |

---

*v4.1 packet generated 2026-05-05 from `hulusi-design-table.xlsx`.*

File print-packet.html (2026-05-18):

# Hulusi Print Packet

Shop-floor bridge for the existing PDF and Markdown packet. Use this page to orient quickly before cutting, voicing, or recording validation data.

Readiness boundary: this packet is ready for HUL-P0/HUL-P1 bench trials, but it is not measured build evidence. Reed pull-down, pipe correction, ergonomic hole shifts, and production CAD exports still require prototype data.

Design authorityhulusi-design-table.xlsx
Named inputs and formula-derived family dimensions.

Build sequenceassembly-manual.md
Fourteen-step shop procedure and failure checks.

Validation logvalidation.csv
Target rows are scaffolded; measured fields remain blank until tests exist.

Explorerexplorer.html
Studio navigation surface for the full repo packet.

## Master Inputs Before Cutting

Variable | Default | Bench value
key_midi | 65 (F4) | _____
mel_bore_ID | 0.500 in | _____
mel_hole_dia | 0.275 in | _____
reed_thickness | 0.008 in | _____
pull_down_cents | -30 cents | _____
correction_pct | 0% | _____

## F-Key Default Cut Targets

Part | Length / size | Notes
Melody tube | 10.05 in, 0.500 in bore | Includes reed-pad allowance.
Drone 1 | 6.82 in, 0.500 in bore | Fifth drone.
Drone 2 | 5.20 in, 0.500 in bore | Leave foot for wax plug.
Melody reed tongue | 0.798 in x 0.157 in x 0.008 in | Brass C26000 starting target.

## Bench Loop

1. Confirm workbook inputs and re-export any derived shop sheets that changed.
2. Cut HUL-P0 reed coupons and record off-pipe pitch before committing to full pipes.
3. Build HUL-P1 melody pipe and compare all seven notes against validation.csv.
4. Update pull_down_cents and correction_pct only from measured prototype evidence.

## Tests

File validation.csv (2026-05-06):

build_id | stage | date | model | key | pipe | condition | target_note | target_freq_hz | measured_freq_hz | cents_error | wax_added_g | tongue_filed_in | action | result | notes
HUL-P0 | reed-coupon |  | coupon | F | Mel | free-reed | F4+pull_down | 343.23 |  |  |  |  | file tongue tip to raise pitch; root to lower |  | Validate brass cut + slot fit before committing to full build.
HUL-P1 | single-pipe |  | solo | F | Mel | all-closed | F4 (tonic) | 349.23 |  |  |  |  | tune reed sharp by ~30 cents; let pipe pull down |  | F-key prototype only.
HUL-P1 | single-pipe |  | solo | F | Mel | hole-1 | G4 | 392.00 |  |  |  |  | measure with hole-1 open only
HUL-P1 | single-pipe |  | solo | F | Mel | hole-7 | F5 | 698.46 |  |  |  |  | octave check
HUL-P2 | full-build |  | F-key | F | Mel | all-closed | F4 | 349.23 |  |  |  |  | wax tune at hole edges if cents_error > 25
HUL-P2 | full-build |  | F-key | F | Mel | hole-1 | G4 | 392.00
HUL-P2 | full-build |  | F-key | F | Mel | hole-2 | A4 | 440.00
HUL-P2 | full-build |  | F-key | F | Mel | hole-3 | A#4 | 466.16
HUL-P2 | full-build |  | F-key | F | Mel | hole-4 | C5 | 523.25
HUL-P2 | full-build |  | F-key | F | Mel | hole-5 | D5 | 587.33
HUL-P2 | full-build |  | F-key | F | Mel | hole-6 | E5 | 659.26
HUL-P2 | full-build |  | F-key | F | Mel | hole-7+thumb | F5 | 698.46
HUL-P2 | full-build |  | F-key | F | Dr1 | free | C5 (5th) | 523.25 |  |  |  |  | fixed drone; voice via reed cut + wax
HUL-P2 | full-build |  | F-key | F | Dr2 | free-uncovered | F5 (oct) | 698.46 |  |  |  |  | wax foot plug for muting
HUL-P3 | water-experiment |  | F-key | F | Mel | all-closed | F4 | 349.23 |  |  |  |  |  |  | Optional water-resonator experiment.

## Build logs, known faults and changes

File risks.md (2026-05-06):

# Hulusi — Risks & Verification Tests (Red Team Output)

> *v4 deliverable. Five risk categories — acoustic, structural, ergonomic, supply, fit/finish — each with concrete failure modes and a verification test. The test is what tells you the risk is closed; without a test, the risk is open.*

> Generated 2026-05-05. Update after each prototype build (HUL-P0 through P4).

---

## 1. Acoustic Risks

### A1. Reed pull-down assumption is wrong
**Risk.** `pull_down_cents = −30 ¢` is a starting estimate. Free-reed pull-down depends on tube/reed coupling, which scales with port impedance and reed-slot leakage. If actual pull-down is closer to −10 ¢ or −60 ¢, every reed in the family will be cut to the wrong target frequency.

**Severity.** High. A 30¢ reed-cut error is detectable by ear and pushes hole-position math out of tolerance for the whole instrument.

**Verification test.**
1. Build HUL-P0 reed coupon at the design-default `pull_down_cents = −30`.
2. Sound the reed *off the pipe* with a controlled air column (manometer at 5–10 cm H₂O).
3. Measure with tuner; record in `validation.csv`.
4. Mount on a calibrated test pipe of known acoustic length; measure played pitch.
5. Compute actual pull-down = `played_pitch − reed_free_pitch` in cents.
6. Update `pull_down_cents` in `Master_Inputs`. Re-cut next reed batch.

**Closed when.** Three reeds cut at the updated `pull_down_cents` produce played pitches within ±10 ¢ of `f_tonic`.

---

### A2. K_imperial = 27,300 for brass C26000 is published-data, not measured
**Risk.** The reed-tongue length formula (`L = √(K·t / f)`) hangs entirely on K_imperial. If the actual brass shim has different cold-rolling history, hardness, or alloy mix, K can drift ±15%. Tongue lengths would then be off by ~7%.

**Severity.** Medium. Mostly absorbed by reed filing during voicing, but starting too far off the target wastes material.

**Verification test.**
1. Cut three reeds at three different lengths (e.g. 0.7 / 0.8 / 0.9 in) from one shim batch.
2. Sound each reed off-pipe; measure free frequency.
3. Fit `K = f · L² / t` per reed; average.
4. If average K differs from 27,300 by >5%, update `reed_K_imperial` in `Master_Inputs`.

**Closed when.** Three independent reed cuts agree on K within ±3%.

---

### A3. Drone pipes pull mouth pressure away from melody
**Risk.** Three reeds breathing from one wind chest may load each other's flow. With drones open, the melody pipe may receive less air, dropping its volume or destabilizing pitch. Traditional Dai builds tune for this; a wooden-gourd build with stiffer walls may behave differently.

**Severity.** Medium-low. Player can compensate with breath, but bad coupling makes the instrument tiring to play.

**Verification test.**
1. On HUL-P2, sound each pipe alone (other reed slots taped shut).
2. Sound all three together; remeasure each pipe's pitch and SPL.
3. If any pipe shifts >15 ¢ between solo and ensemble conditions, the wind chest is undersized — increase `gourd_volume_in3`.

**Closed when.** All three pipes pitch-stable within ±15 ¢ between solo and ensemble.

---

### A4. End-correction coefficient mismatch
**Risk.** Default `end_corr_k = 0.6` is the unflanged Levine-Schwinger value. Real pipe-foot conditions (flush in a stand, near body, partly muted by player's leg) may push effective k toward 0.85 or below 0.5.

**Severity.** Low. Whole-instrument flat by ~10 ¢ if mis-applied; absorbed by `correction_pct`.

**Verification test.**
1. After HUL-P1 measurements come in, fit `end_corr_k` from the all-holes-closed pitch error.
2. Compare to default; document delta.

**Closed when.** Fitted `end_corr_k` documented in design.md "Empirical Corrections" section.

---

## 2. Structural Risks

### S1. Pakkawood tube splits during boring
**Risk.** Pakkawood is dyed and resin-stabilized. Long deep-bore drilling generates heat; resin can soften and gum the bit, or the dowel can split along its grain if clamping is uneven.

**Severity.** Medium. One ruined blank costs $10–15 and a lost hour.

**Verification test.**
1. Drill the bore on the *first* pipe blank with a 0.500 in twist drill, peck cycle (0.25 in advance + retract every cycle), feed rate 2 in/min.
2. Inspect for heat discoloration, gumming, and split lines.
3. If gumming: sub a brad-point bit or apply mineral-oil flood.
4. If splitting: rotate dowel 90° and re-clamp on flats.

**Closed when.** Three consecutive bores complete with no splits, no heat scoring, and concentricity at both ends within 0.005 in.

---

### S2. Reed shim cracks at root over time
**Risk.** Brass C26000 0.008 in shim subjected to repeated flexing at the root will work-harden and crack. Lifetime varies — could be hours or years.

**Severity.** Medium. Reeds are consumables; design supports replacement.

**Verification test.**
1. Mount a HUL-P0 reed and sound it for 60 minutes total play time.
2. Inspect tongue root with 10× loupe weekly during the next 12 weeks.
3. Document any cracking with calendar date and play hours.

**Closed when.** Reed lifetime estimate (in play hours) recorded; replacement procedure in assembly-manual.md.

---

### S3. Walnut gourd halves separate at glue line
**Risk.** Two-half hollow gourd is glued along an equator joint. Pressure stresses (from blowing) and humidity cycling can pop the joint, causing leaks and ruining tuning.

**Severity.** High. A leaky gourd makes the instrument unplayable.

**Verification test.**
1. Glue HUL-P2 gourd halves with hide glue.
2. Pressure-test by submerging gourd (mouth + sockets sealed) in water and pulling slow vacuum (~10 inHg) externally — bubbles indicate leaks.
3. Re-test after 30, 60, 90 days under varied humidity.

**Closed when.** No leaks at 90-day inspection. If leaks appear, switch to epoxy or add interior sealant.

---

### S4. Reed frame plate flexes and breaks wax seal
**Risk.** 0.040 in brass frame plate may flex under playing pressure, breaking the beeswax-rosin seal between plate and pipe top. Air leaks → flat pitch and mushy attack.

**Severity.** Medium. Detectable by listening; fix is to re-wax.

**Verification test.**
1. Apply pressure (5 cm H₂O) at the mouthpiece while watching the frame-plate seal under raking light.
2. Listen for air-hiss leaks at each pipe-to-frame joint.
3. Repeat after 30, 90 days.

**Closed when.** No detectable hiss or visible plate flex at any pipe-to-frame joint after 90 days.

---

## 3. Ergonomic Risks

### E1. Finger holes computed by physics may not match hand
**Risk.** `Holes!E:E` places hole positions where the *acoustics* says they belong. For an F-key hulusi these are 4.78 in to 8.51 in from the foot — that's 3.7 in of finger-hole span across 6 front holes. A 5th-percentile-female hand (4.5 in span fingertip-to-fingertip with fingers extended) may struggle.

**Severity.** Medium. Adult average hand spans accommodate easily; kids and small hands may not.

**Verification test.**
1. After HUL-P1 hole layout is locked, hand the instrument to three players: one large-hand (>7.5 in span), one average (~6.5 in), one small (~5 in).
2. Each plays the diatonic scale at moderate tempo.
3. Document any discomfort or missed-hole errors per player.

**Closed when.** All three players play the scale without strain or position errors. If small-hand player struggles, design a "compact" variant with reduced bore (`mel_bore_ID = 0.45 in`) to shorten the pipe.

---

### E2. Drone 2 wax-plug fingernail action is awkward
**Risk.** Traditional waxable drone control requires the player to scrape wax with a fingernail mid-phrase. Wax hardness, plug geometry, and nail length all factor in.

**Severity.** Low. Instrument is playable without the wax-control feature; it's a refinement.

**Verification test.**
1. After HUL-P3 wax plug is shaped, play a 30-second phrase with at least 3 mute/unmute transitions.
2. Document: fingernail catches plug? Plug too soft (smears)? Too hard (won't scrape)?
3. Adjust wax:rosin ratio (default 4:1; try 5:1 softer or 3:1 harder).

**Closed when.** Player can mute/unmute drone 2 cleanly within one beat of intent.

---

### E3. Mouthpiece geometry uncomfortable for extended playing
**Risk.** Default mouthpiece is a 0.5 in OD boxwood/horn cylinder with 0.25 in bore. Lip fatigue or tooth-chatter from extended play (>10 min sessions) will register before formal validation.

**Severity.** Low. Easy to swap mouthpiece insert.

**Verification test.**
1. After HUL-P2 build, play 15-minute continuous session.
2. Note any lip/tongue/jaw fatigue or saliva pooling issues.
3. If issues: try thinner-walled mouthpiece (0.4 in OD with 0.27 in bore) or angled mouthpiece.

**Closed when.** Player completes 30-minute session with no ergonomic complaints.

---

## 4. Supply Risks

### V1. Pakkawood availability is single-sourced
**Risk.** Cousineau Wood Products and Bell Forest Products are the named suppliers in `sourcing.csv`. Both are small specialty operations; either could discontinue 1-inch round dowel stock. Substitution moves to hard maple change tone color.

**Severity.** Medium. Design works in maple; voicing will need re-validation.

**Verification test.**
1. Build one HUL-P1 in pakkawood and one in hard maple at the same key.
2. Compare measured pitches and tonal character.
3. Document dimensional/sonic differences.

**Closed when.** Maple-substitution data (cents shift, tonal note) added to `sourcing.csv` for reference.

---

### V2. Brass shim 0.008 in has alloy variation across vendors
**Risk.** McMaster 9534K27 spec is "C26000 cartridge brass" but cold-roll temper can vary. Different reels may have different K constants (see A2).

**Severity.** Low. K is updateable in `Master_Inputs`.

**Verification test.**
1. Document supplier and lot number on every reed batch.
2. Run A2 verification on each new lot.
3. Compare K constants across lots; flag if drift >5%.

**Closed when.** Two independent lots verified within ±3% of each other on K.

---

### V3. Beeswax + rosin ratio drift
**Risk.** Beeswax and rosin from natural sources vary in hardness. A summer-harvested beeswax behaves differently from winter; "violin grade" rosin from different makers has different melt points.

**Severity.** Low. Easy to re-cook the wax mix.

**Verification test.**
1. Document wax + rosin source/date on every wax-batch label.
2. Test new batch by cooling on a slate slab and pressing thumb at room temp — should leave a faint print but not deform.

**Closed when.** Recipe document in `assembly-manual.md` includes a temperature + vendor reference for "right" hardness.

---

## 5. Fit & Finish Risks

### F1. Finger-hole edges raise too much when reamed
**Risk.** Reaming undersized holes to final 0.275 in dia can tear or chip the pakkawood interior, creating sharp edges that hurt the player's fingertip and disrupt airflow.

**Severity.** Medium. Easy to fix with a chamfer; bad if not noticed.

**Verification test.**
1. After hole reaming, run a fingertip across each hole interior.
2. Inspect with 10× loupe for tear-out.
3. Apply 0.030 in chamfer with a deburring tool.

**Closed when.** All 7 holes pass the fingertip-feel test and visual inspection.

---

### F2. Wax seal ages and yellows visibly at gourd-pipe joints
**Risk.** Beeswax-rosin mix oxidizes and yellows over years. Functional, but visually distracting on a hardwood gourd.

**Severity.** Cosmetic. Doesn't affect play.

**Verification test.**
1. Photograph wax joints at build time, 30, 90, 365 days.
2. Document color shift.
3. Optional refinement: cover wax with a thin walnut veneer collar.

**Closed when.** Decision documented: leave wax visible (functional aesthetic) or cover with collar (refined aesthetic).

---

### F3. Drone 2 wax plug looks unfinished
**Risk.** A blob of yellow wax at one pipe foot reads as "unfinished" to first-time viewers. This is the *traditional* hulusi look but may not match the rest of the build's aesthetic.

**Severity.** Cosmetic.

**Verification test.**
1. Photograph the finished HUL-P2 with and without wax plug.
2. Show to 3 viewers; document first impression.
3. Optional: shape wax into a turned dome, or recess plug into a counterbore.

**Closed when.** Aesthetic decision documented and reflected in `assembly-manual.md`.

---

### F4. Tassel and binding-ring detail clash with restrained build aesthetic
**Risk.** Traditional hulusi has bright silk tassel + decorative tubing. Tony's typical build aesthetic is more restrained walnut + brass.

**Severity.** Cosmetic / personal preference.

**Verification test.**
1. Build HUL-P2 first without tassel; photograph.
2. Add tassel; photograph.
3. Decide which to ship.

**Closed when.** Decision documented in README hero image caption.

---

## Summary

| Category | Open risks | Highest-severity item |
|---|---:|---|
| Acoustic | 4 | A1 (reed pull-down assumption) |
| Structural | 4 | S3 (gourd glue-line failure) |
| Ergonomic | 3 | E1 (finger-hole hand-fit) |
| Supply | 3 | V1 (pakkawood single-sourced) |
| Fit & finish | 4 | F1 (hole-edge tear-out) |
| **Total** | **18** | |

The highest-leverage tests in time-order are:
1. **A1 + A2 (HUL-P0)** — settles `pull_down_cents` and `reed_K_imperial` for the entire family.
2. **S1 (HUL-P0/P1)** — confirms pakkawood machining process before committing all 3 tubes.
3. **S3 (HUL-P2)** — gourd glue-line is a single point of failure for the whole instrument.

Test these three before committing any further. Everything else can be deferred to its corresponding prototype stage.

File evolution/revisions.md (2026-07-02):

# Revision Register — hulusi

| Rev | Date | Parent | Delta | Downstream artifacts invalidated |
| --- | --- | --- | --- | --- |
| A | 2026-07-01 | — | Stage 0 intake of current masters (cad/hulusi_master.scad + hulusi-design-table.xlsx + newly generated wolfram/hulusi-wolfram-model.wl). README status corrected to L1 concept packet (see design-intent.md / mcp-session-log.md). | none (no alpha/beta/production artifacts exist yet) |

Stage 0 only. Gate A has not been run; no Alpha compiles, vendor quotes, or production lock exist for this product. HUL-P0/HUL-P1 measured evidence remains the blocking gate for any promotion beyond L1.

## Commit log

2026-05-06 v4 update
    [family-spec.csv]
2026-05-18 Add hulusi studio explorer
    * Add hulusi studio explorer
    * Fix hulusi explorer review gates
    ---------
    [family-spec.csv]
2026-05-18 Add hulusi HUL-P0/HUL-P1 empirical loop packet (#2)
    [p0-reed-coupon-log.csv, p1-single-melody-pipe-control-log.csv, safety-gates.csv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]
2026-05-18 Add Round 30 hulusi empirical loop gates (#4)
    [family-spec.csv, p0-reed-coupon-log.csv, p1-single-melody-pipe-control-log.csv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]
2026-05-30 v5-migrate(hulusi): register + mcp-log + status (Refs instrument-maker#184) (#5)
    [visual-output-register.csv]
2026-05-31 wolfram-rename(hulusi): unique {slug}-starter.wl + dedupe + ref fixes (cloud-sync naming) (#6)
    [visual-output-register.csv]
2026-05-31 Add image-gen concept prompt; wire explorer images
2026-06-21 Wire 4 rendered concept image(s) into explorer gallery
2026-07-02 V5 packet refresh: status honesty correction, Wolfram model, provenance, evolution intake
    Validator: python3 validate_v5_packet.py . --slug hulusi -> 0 failures, 12 pre-existing warnings unchanged (all pending_measurement authority WARNs, expected per V5 standard). Corrected README status from "L2 V5 build-packet candidate" to "L1 concept packet" per the skill's hulusi-bawu-stopped-pipe-free-reed reference: every acoustic-law row (family-spec.csv, p0-reed-coupon-log.csv, p1-single-melody-pipe-control-log.csv) is unknown_requires_measurement/measurement_required with no HUL-P0/HUL-P1 bench evidence yet, so L2_bench_validated is not earned. Generated wolfram/hulusi-wolfram-model.wl via generat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
    [visual-output-register.csv]
